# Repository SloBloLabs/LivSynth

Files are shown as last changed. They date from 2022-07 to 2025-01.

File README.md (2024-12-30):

# Youtube

Watch the related [Demo Video] on Youtube for a workout in musical context.

S54 (Liv's Synth - A Demo) (https://youtu.be/09B7NOryfzA)

Watch the corresponding [Video Manual] on Youtube for a detailed feature explanation.

S54 (Liv's Synth - A Demo) (https://youtu.be/lYTFUqn5oQk)

[Demo Video]: https://youtu.be/7tzhh7atj4o
[Video Manual]: https://youtu.be/lYTFUqn5oQk

# Build Instructions

How to convert a CubeMX / CubeIDE project to GNU ARM Toolchain with CMake, openocd and VS Code

Prerequisites

Available on PATH
 - ARM toolchain
 - make
 - cmake
 - openocd

VS Code extensions
 - MS C/C++
 - MS C/C++ Extension Pack
 - Cortex Debug

---

Workflow

Copy to project directory:
 - README.md
 - Makefile
 - CMakeLists.txt
 - cmake folder with arm toolchain cmake directives
 - .gitignore file
 - swvtrace.sh
 - svd file (optional)
 - folder .vscode/launch.json and adapt settings
 - folder "App"

then
 - Adapt settings in CMakeLists.txt header
 - rename myAppMain [.hpp/.cpp]
 - include myAppMain.hpp in Core/Src/main.c
 - add projectMain() to main.c (right before while loop)
 - right click CMakeLists.txt -> configure all projects
 - start coding

Tested on
 - Mac
 - Linux

2022-03-08: There is an issue using ARM Toolchain 11.2.1: https://community.arm.com/support-forums/f/compilers-and-libraries-forum/52377/internal-compiler-errors-with-arm-none-eabi-gcc-11-2-2022-02-on-macs-with-apple-silico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
Stick with 10.3 for now!!
2022-11-13: The issue is solved within Toolchain version 11.3.1

---

Upload to github
 - git init
 - git add .
 - git config user.name "<<username>>"
 - git config user.email "<<email>>"
 - git commit -m "First commit"
 - git branch -M main
 - git remote add origin https://github.com/SloBloLabs/<"ProjectRepo">.git
 - git push -u origin main

--

Update github access token
 - git remote remove origin
 - git remote add origin https://oauth2:<<new oauth token>>@github.com/<<username>>/<<reponame>>.git
 - git remote -v

--

Bake a new release on Github:
git tag <tagname> // e.g. v0.2.1
git push origin <tagname>

--
# STM32 USB Composite device

Composite USB interface:

1 configuration
3 interfaces (2*CDC + 1*MIDI)
6 endpoints

CDC:
 - 2 interfaces
   - 0: communications control
     - 1 endpoint 0x82
   - 1: communications data
     - 2 endpoints 0x01 + 0x81 (BULK)
 - 4 endpoints overall
   - EP0
   - EP1
   - EP3 (in only: 0x83)

MIDI:
 - 1 interface
   - 0: Audio/Streaming
     - 2 endpoints 0x02 + 0x83 (BULK)
 - 3 endpoints overall
   - EP0
   - EP2

# Build Instructions

Use the ibom tool inside the hardware section of the repository to track your work!
## Power
 - Place USB Micro Connector J21
 - Place all components from power section
   - U8
   - D12
   - FB1
   - U1
   - J24, J24, J12, J7
   - C49, C52, C32, C33, C1, C2, C3, C7
   - R1, R2, R11
   - SW7
 - Check voltages at J201, do proceed if everything is ok!

## Assembly of backside
 - assemble all components (except 5mm LEDs!) on the backside of the mainboard, preferably using the following order:
   - SMD components
   - resistors
   - diodes
   - DIP socket and DIP components
   - transistors (Q4/Q5, Q8/Q9 and Q11/Q12 must be matched)
   - tempco resistor
   - pin headers
   - capacitors

## Assemply of frontside
 - assemble potentiometers, trimmers, spacers and switches of the mainboard, DO NOT SOLDER THEM YET!
 - put the faceplate on top and make sure all components incl. trimmers fit into the wholes
 - fasten the M2.5 screws in the corners
 - turn the set around and solder everthing
 - remove the faceplate again

## Assmebly of speaker
 - First put screws from backside, hex nuts on the front side and tighten them
 - solder the hex nuts to the solder pads
 - apply two pieces of bell wire of about 5cm in lenght to the speakers solder pads
 - remove screws and mount the speaker to the frontside using the screws the other way around
 - if using the battery holder you may need to shorten one of the screws to make it fit
 - connect the loose ends of speaker wires to J4

## LEDs
 - assemble the 5mm LEDs on the backside
 - bend their heads in a 180° U-turn into the holes behind the transparent potentiometers, so they can emit as much light as possible into their shafts

## Flashing the firmware
 - make sure, dfu-util (https://dfu-util.sourceforge.net) is installed on your machine
   - alternatively, you can use stm32 cube programmer (https://www.st.com/en/development-tools/stm32cubeprog.html). I will not further explain this way, but it is a little more user friendly and pretty straight forward.
 - switch off the synthesizer
 - pull the run/program toggle switch next to the micro USB port to lower (program) position
 - connect a USB cable between the synth and your computer
 - switch on the synth again
 - execute the following command:
```
dfu-util -a 0 -s 0x08000000 -D <path to LivSynth.bin>
```
 - The output in the console shoud look similar to this:
```
dfu-util -a 0 -s 0x08000000 -D build/LivSynth.bin
dfu-util 0.11

Copyright 2005-2009 Weston Schmidt, Harald Welte and OpenMoko Inc.
Copyright 2010-2021 Tormod Volden and Stefan Schmidt
This program is Free Software and has ABSOLUTELY NO WARRANTY
Please report bugs to http://sourceforge.net/p/dfu-util/tickets/

dfu-util: Warning: Invalid DFU suffix signature
dfu-util: A valid DFU suffix will be required in a future dfu-util release
Opening DFU capable USB device...
Device ID 0483:df11
Device DFU version 011a
Claiming USB DFU Interface...
Setting Alternate Interface #0 ...
Determining device status...
DFU state(10) = dfuERROR, status(10) = Device's firmware is corrupt. It cannot return to run-time (non-DFU) operations
Clearing status
Determining device status...
DFU state(2) = dfuIDLE, status(0) = No error condition is present
DFU mode device DFU version 011a
Device returned transfer size 2048
DfuSe interface name: "Internal Flash  "
Downloading element to address = 0x08000000, size = 49412
Erase           [=========================] 100%        49412 bytes
Erase    done.
Download        [=========================] 100%        49412 bytes
Download done.
File downloaded successfully
```
 > Hint: if you are building the firmware from the repo, the DFU command is called by simply writing
```
make dfu
```
 - switch off the synth and remove the USB cable
 - pull the run/program switch up (run) again
 - switch on the synth
 - Click <kbd>shift</kbd> + <kbd>run</kbd> to enter sequence control mode
 - press and hold button <kbd>8</kbd> for more than 2 seconds. This will initialize the sequencer program in flash. The synth is now reset.
 - Press <kbd>run</kbd> again to get back to pattern mode

## Test & Calibration
 - connect a 9V center negative power supply to the barrel jack
 - switch on the device and wait a moment. Turn it off again if you see anything suspicious. ("smoke test")
 - At least the keyboard LEDs should light up in white colour and the LFO LEDs are blinking
### VCO
  - SAW amplitude
  - SQUARE amplitude
  - fine tune & tracking
    - Press a button and tune it to the lowest note (red) using the tune knob
    - Press another button and tune it to the red note two octaves higher
    - Press a third button and tune it to the highest red note
### VCA
  - balance...

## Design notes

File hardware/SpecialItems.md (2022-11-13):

SpecialItems

Alpha Potentiometers
RD901F-40-15K-B10K
RD901F-40-15K-B100K

see
https://www.thonk.co.uk/shop/alpha-9mm-pots-vertical-t18/
https://www.alibaba.com/product-detail/RD901F-40-15K-B10K-00DL1-alternative_1600283009362.html

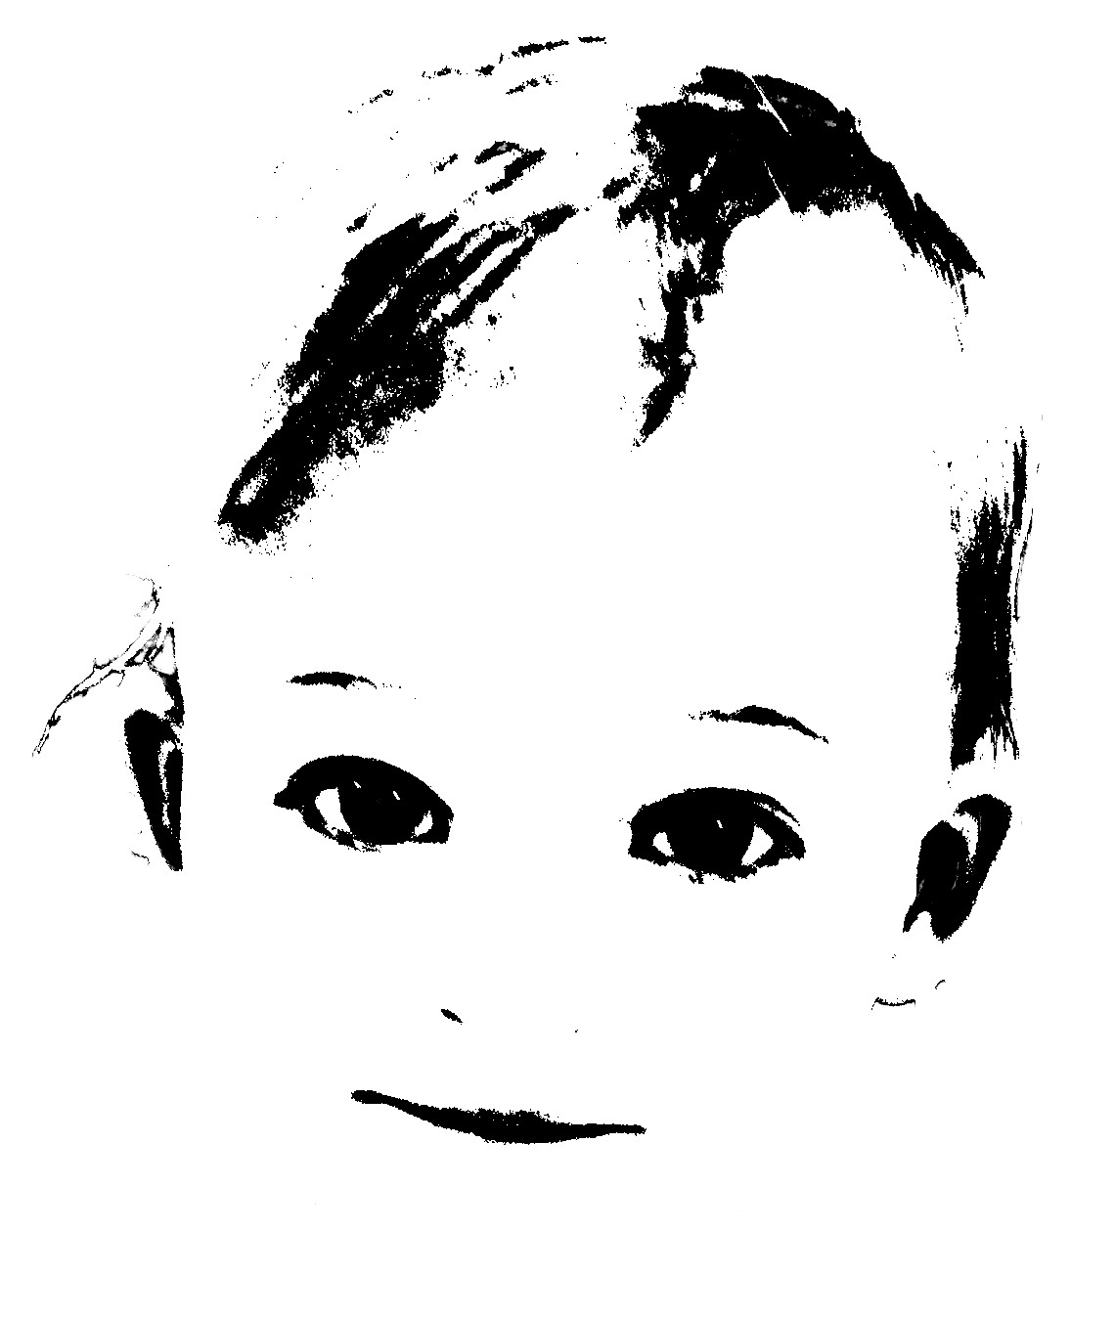
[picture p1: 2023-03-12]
hardware/Faceplate/LivGreyscale.JPG

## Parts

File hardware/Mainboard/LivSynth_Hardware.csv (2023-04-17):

Id | Designator | Footprint | Quantity | Designation | Supplier and ref
1 | RGB_Pot6,RGB_Pot5,RGB_Pot3,RGB_Pot8,RGB_Pot1,RGB_Pot9,RGB_Pot4,RGB_Pot2,RGB_Pot7 | TC002-N11AS2XT-RGB | 9 | TC002-N11AS2XT-RGB
2 | SW2 | SW_Toggle_MS500 | 1 | SW_SPST
3 | NT1,NT4,NT5,NT3,NT2 | NetTie-2_SMD_Pad0.5mm | 5 | NetTie_2
4 | RV17,RV16,RV15,RV2 | Potentiometer_Bourns_3296W_Vertical | 4 | 100K
5 | LS1 | LSM-50M NO-B | 1 | LSM-50M/NO-B 8R (<32R) 1W
6 | SW6 | E-Switch_TL1105SP | 1 | SW_Push
7 | RV22,RV19,RV13,RV14,RV3,RV8,RV18,RV20 | Alpha_RD901F | 8 | 100K
8 | RV7,RV6,RV10,RV5,RV11 | RV141F-40-20BL | 5 | 100K
9 | RV1 | Potentiometer_Bourns_3296W_Vertical | 1 | 1K
10 | SW4,SW3,SW1 | SW_Toggle_MS500 | 3 | SW_SPDT
11 | RV21 | Alpha_RD901F | 1 | 10K
12 | RV9,RV4 | RV141F-40-20BL | 2 | 10K
13 | J3,J1,J2 | Thonkiconn_PJ398SM | 3 | PJ398SM
14 | H2,H1,H6,H5 | MountingHole_3.2mm_M3 | 4 | MountingHole
15 | RV12 | Potentiometer_Bourns_3296W_Vertical | 1 | 100
16 | R46,R16,R25,R27,R35,R48,R15,R45 | R_Axial_DIN0207_L6.3mm_D2.5mm_P7.62mm_Horizontal | 8 | 1K
17 | D10,D5,D8,D9,D2,D1 | LED_D5.0mm | 6 | LED
18 | R75,R76,R70,R67 | R_Axial_DIN0207_L6.3mm_D2.5mm_P7.62mm_Horizontal | 4 | 100
19 | C43,C7,C58,C37,C34,C59,C35,C18,C26,C61,C12,C17,C62,C27,C31,C6,C4,C16,C30,C3 | C_Rect_L7.2mm_W2.5mm_P5.00mm_FKS2_FKP2_MKS2_MKP2 | 20 | 100n
20 | R77 | R_Axial_DIN0207_L6.3mm_D2.5mm_P7.62mm_Horizontal | 1 | 4k7
21 | R83,R80,R10,R72,R66,R40,R11,R37,R26,R21,R32,R2,R78,R13,R1,R64,R87,R22,R79,R19,R82,R4,R47,R56,R81,R12,R39,R3,R38,R51 | R_Axial_DIN0207_L6.3mm_D2.5mm_P7.62mm_Horizontal | 30 | 100K
22 | R42,R31,R36,R24,R54,R33 | R_Axial_DIN0207_L6.3mm_D2.5mm_P7.62mm_Horizontal | 6 | 2K
23 | R109,R30,R106,R107,R105,R29,R34,R73,R69,R89,R113,R114,R111,R112,R108,R68,R110 | R_Axial_DIN0207_L6.3mm_D2.5mm_P7.62mm_Horizontal | 17 | 10K
24 | R125,R131,R103,R98,R101,R129,R117,R121,R100,R91,R127,R99,R123,R14,R88,R104,R102,R119,R97 | R_Axial_DIN0207_L6.3mm_D2.5mm_P7.62mm_Horizontal | 19 | 220
25 | R41 | R_Axial_DIN0207_L6.3mm_D2.5mm_P7.62mm_Horizontal | 1 | 6K2
26 | R7,R9 | R_Axial_DIN0207_L6.3mm_D2.5mm_P7.62mm_Horizontal | 2 | 20K
27 | U2,U4,U6,U1,U5 | SOIC-14_3.9x8.7mm_P1.27mm | 5 | TL074
28 | Q6,Q12,Q15,Q4,Q11,Q5,Q10,Q13,Q7,Q16,Q1,Q2,Q14,Q17 | TO-92_Inline | 14 | 2N3904
29 | C14,C23,C24 | C_Rect_L7.2mm_W4.5mm_P5.00mm_FKS2_FKP2_MKS2_MKP2 | 3 | 270n
30 | C1,C9,C41,C19,C2,C33,C32 | C_Rect_L7.2mm_W5.5mm_P5.00mm_FKS2_FKP2_MKS2_MKP2 | 7 | 1u
31 | D12 | D_SMC_Handsoldering | 1 | SS310
32 | R90,R130,R122,R124,R126,R120,R118,R128,R116 | R_Axial_DIN0207_L6.3mm_D2.5mm_P7.62mm_Horizontal | 9 | 470
33 | R28,R74,R92,R52,R93 | R_Axial_DIN0207_L6.3mm_D2.5mm_P7.62mm_Horizontal | 5 | 4K7
34 | BT1 | BatteryHolder_Eagle_12BH611-GR | 1 | 9V
35 | R58 | R_Axial_DIN0207_L6.3mm_D2.5mm_P7.62mm_Horizontal | 1 | 150K
36 | U14,U13 | SOIC-16_3.9x9.9mm_P1.27mm | 2 | 74HC165
37 | J21 | USB_Micro-B_Wuerth_629105150521 | 1 | USB_B_Micro
38 | J13,J9,J16,J15,J19,J11,J18,J22,J17,J10,J8 | PinHeader_1x02_P2.54mm_Vertical | 11 | Jumper
39 | D11,D6,D7 | D_DO-35_SOD27_P7.62mm_Horizontal | 3 | 1N4148
40 | R59,R18,R17 | R_Axial_DIN0207_L6.3mm_D2.5mm_P7.62mm_Horizontal | 3 | 47K
41 | J24 | PinHeader_1x02_P2.54mm_Vertical | 1 | 3V3
42 | C10 | CP_Radial_D8.0mm_P3.50mm | 1 | 33u
43 | R44 | R_Axial_DIN0207_L6.3mm_D2.5mm_P7.62mm_Horizontal | 1 | 68K
44 | Q8,Q9 | TO-92_Inline | 2 | 2N3906
45 | R71 | R_Axial_DIN0207_L6.3mm_D2.5mm_P7.62mm_Horizontal | 1 | 68k
46 | R60 | R_Axial_DIN0207_L6.3mm_D2.5mm_P7.62mm_Horizontal | 1 | 100k
47 | U10,U11 | TSSOP-28_4.4x9.7mm_P0.65mm | 2 | PCA9685PW
48 | SW8,SW7 | SW_E-Switch_EG1224_SPDT_Angled | 2 | SW_SPDT
49 | C49,C45,C15 | CP_Radial_D8.0mm_P3.50mm | 3 | 10u
50 | C29 | CP_Radial_D8.0mm_P3.50mm | 1 | 470u
51 | R49 | R_Axial_DIN0207_L6.3mm_D2.5mm_P7.62mm_Horizontal | 1 | 820K
52 | J7 | BarrelJack_CUI_PJ-102AH_Horizontal | 1 | Barrel_Jack_Switch
53 | R63,R62 | R_Axial_DIN0207_L6.3mm_D2.5mm_P7.62mm_Horizontal | 2 | 1M
54 | C5,C20 | C_Rect_L7.2mm_W2.5mm_P5.00mm_FKS2_FKP2_MKS2_MKP2 | 2 | 1n
55 | R50 | R_Axial_DIN0207_L6.3mm_D2.5mm_P7.62mm_Horizontal | 1 | 100R
56 | R55 | R_Axial_DIN0207_L6.3mm_D2.5mm_P7.62mm_Horizontal | 1 | 2K2
57 | Y1 | Crystal_SMD_3225-4Pin_3.2x2.5mm_HandSoldering | 1 | ABM8-16.000MHZ-D1X-T
58 | U7 | SOP-16_3.9x9.9mm_P1.27mm | 1 | LM13700
59 | J25 | PinHeader_1x02_P2.54mm_Vertical | 1 | 9V
60 | R85,R86 | R_Axial_DIN0207_L6.3mm_D2.5mm_P7.62mm_Horizontal | 2 | 2K7
61 | R23,R43 | R_Axial_DIN0207_L6.3mm_D2.5mm_P7.62mm_Horizontal | 2 | 470K
62 | R6,R5 | R_Axial_DIN0207_L6.3mm_D2.5mm_P7.62mm_Horizontal | 2 | 360
63 | C21,C13,C36 | C_Rect_L7.2mm_W2.5mm_P5.00mm_FKS2_FKP2_MKS2_MKP2 | 3 | 10n
64 | R57 | R_Axial_DIN0207_L6.3mm_D2.5mm_P7.62mm_Horizontal | 1 | 24K
65 | C11,C8 | C_Disc_D3.0mm_W1.6mm_P2.50mm | 2 | 1p
66 | TH1 | R_Axial_DIN0207_L6.3mm_D2.5mm_P7.62mm_Horizontal | 1 | 2K 3300ppm LT16S202F33
67 | FB1 | L_0603_1608Metric | 1 | 120R@100MHz
68 | R61 | R_Axial_DIN0207_L6.3mm_D2.5mm_P7.62mm_Horizontal | 1 | 10R
69 | C25 | C_Rect_L7.2mm_W5.5mm_P5.00mm_FKS2_FKP2_MKS2_MKP2 | 1 | 270n
70 | R84 | R_Axial_DIN0207_L6.3mm_D2.5mm_P7.62mm_Horizontal | 1 | 330K
71 | R8,R65 | R_Axial_DIN0207_L6.3mm_D2.5mm_P7.62mm_Horizontal | 2 | 390
72 | R53 | R_Axial_DIN0207_L6.3mm_D2.5mm_P7.62mm_Horizontal | 1 | 8K2
73 | R20 | R_Axial_DIN0207_L6.3mm_D2.5mm_P7.62mm_Horizontal | 1 | 82K
74 | C22 | CP_Radial_D8.0mm_P3.50mm | 1 | 4u7
75 | C52 | CP_Radial_D8.0mm_P3.50mm | 1 | 22u
76 | C28 | C_Disc_D3.0mm_W1.6mm_P2.50mm | 1 | 47p
77 | U9 | LQFP-64_10x10mm_P0.5mm | 1 | STM32F405RGT6
78 | J12 | PinHeader_1x02_P2.54mm_Vertical | 1 | VGND
79 | D3 | LED_D5.0mm-4_RGB | 1 | LED_RKGB
80 | U8 | SOT-223-3_TabPin2 | 1 | LM1117-3.3
81 | U3 | DIP-8_W7.62mm_Socket | 1 | LM386

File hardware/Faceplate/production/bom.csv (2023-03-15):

Designator | Footprint | Quantity | Value | LCSC Part #
_250, _249, _248, _247, _246, _245, _244, _243, _242, _241, _240, _239, _238, _237, _236, _235, _234, _233, _232, _231, _230, _229, _228, _227, _226, _225, _224, _223, _222, _221, _220, _219, _218, _217, _216, _215, _214, _213, _212, _211, _210, _209, _208, _207, _206, _205, _204, _203, _202, _201, _200, _199, _198, _197, _196, _195, _194, _193, _192, _191, _190, _189, _188, _187, _186, _185, _184, _183, _182, _181, _180, _179, _178, _177, _176, _175, _174, _173, _172, _171, _170, _169, _168, _167, _166, _165, _164, _163, _162, _161, _160, _159, _158, _157, _156, _155, _154, _153, _152, _151, _150, _149, _148, _147, _146, _145, _144, _143, _142, _141, _140, _139, _138, _137, _136, _135, _134, _133, _132, _131, _130, _129, _128, _127, _126, _125, _124, _123, _122, _121, _120, _119, _118, _117, _116, _115, _114, _113, _112, _111, _110, _109, _108, _107, _106, _105, _104, _103, _102, _101, _100, _99, _98, _97, _96, _95, _94, _93, _92, _91, _90, _89, _88, _87, _86, _85, _84, _83, _82, _81, _80, _79, _78, _77, _76, _75, _74, _73, _72, _71, _70, _69, _68, _67, _66, _65, _64, _63, _62, _61, _60, _59, _58, _57, _56, _55, _54, _53, _52, _51, _50, _49, _48, _47, _46, _45, _44, _43, _42, _41, _40, _39, _38, _37, _36, _35, _34, _33, _32, _31, _30, _29, _28, _27, _26, _25, _24, _23, _22, _21, _20, _19, _18, _17, _16, _15, _14, _13, _12, _11, _10, _9, _8, _7, _6, _5, _4, _3, _2, |  | 250
H1, H2, H5, H6 | MountingHole_3.2mm_M3 | 4 | MountingHole

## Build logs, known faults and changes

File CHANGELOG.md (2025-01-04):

v0.2.5
- Play incoming midi notes in idle mode
- Store last incoming midi note to selected step
- Cosmetics in USB device descriptor

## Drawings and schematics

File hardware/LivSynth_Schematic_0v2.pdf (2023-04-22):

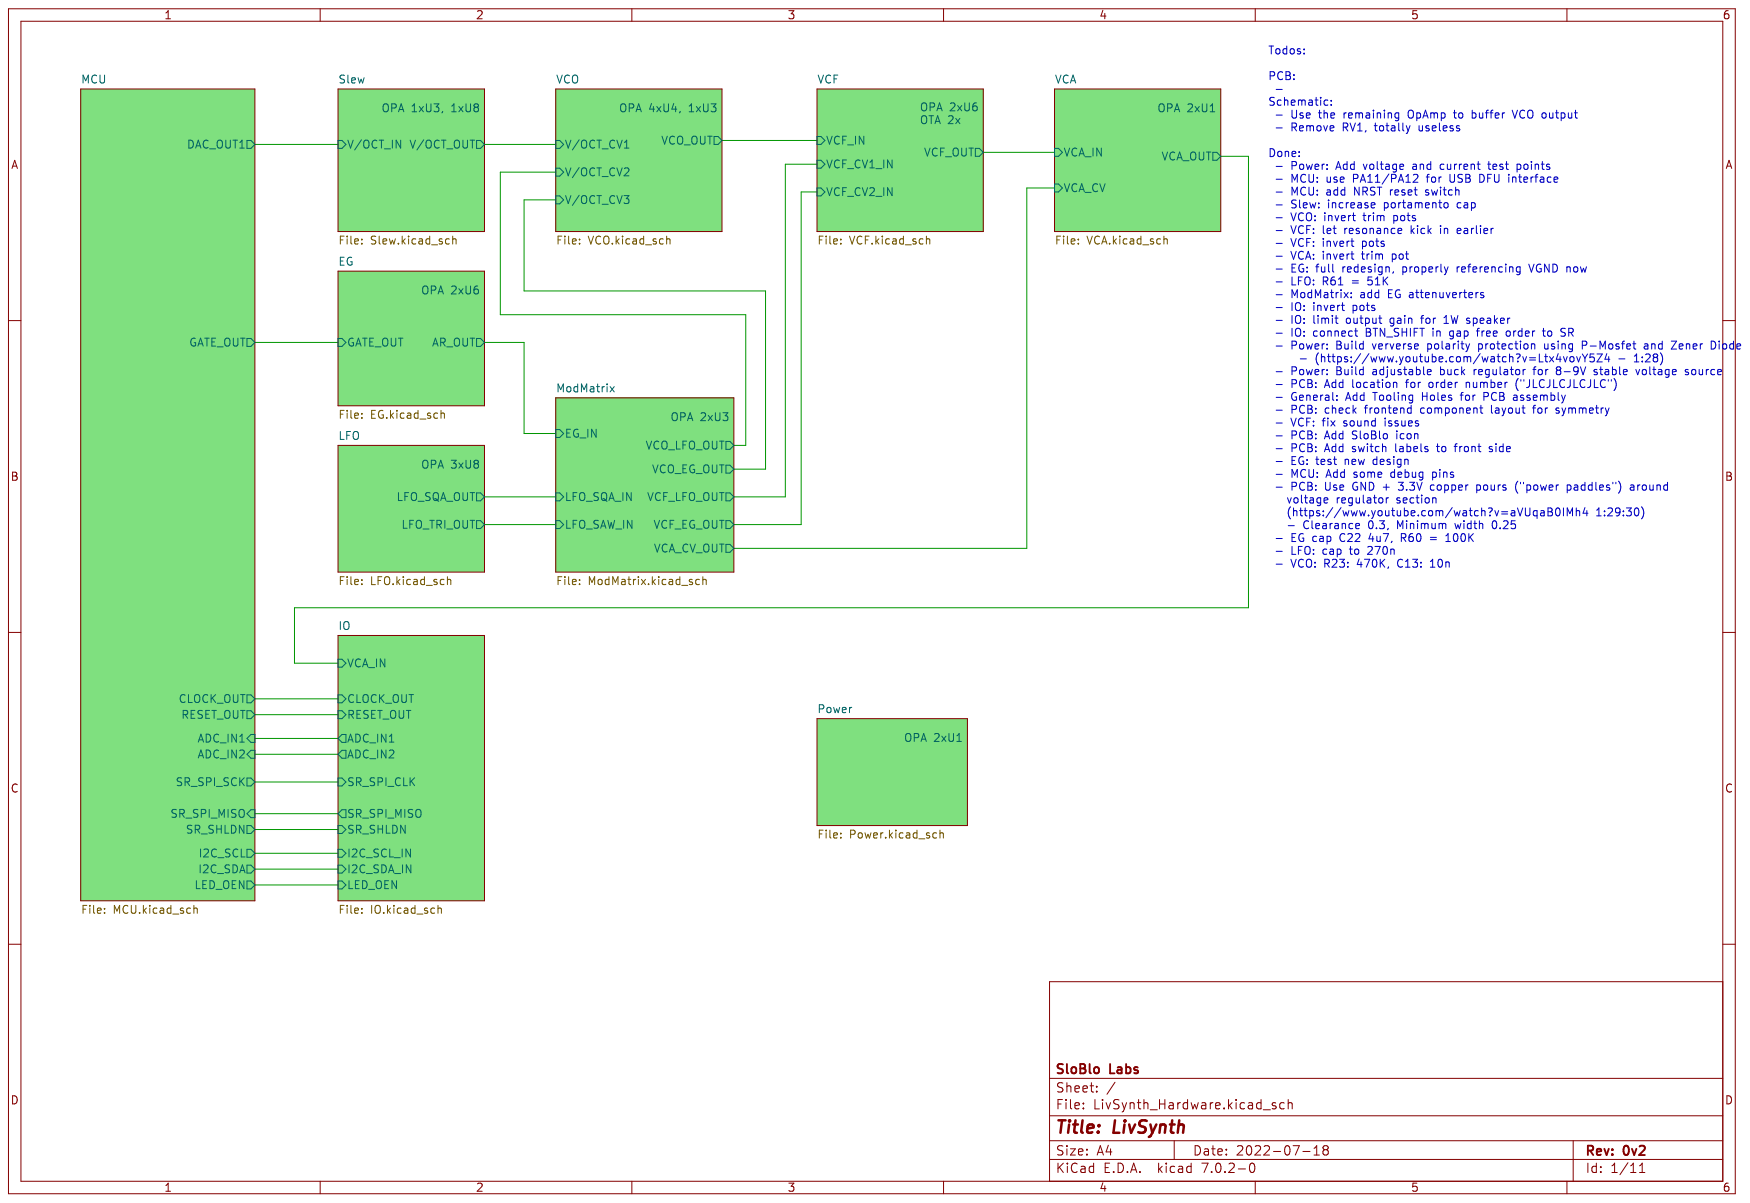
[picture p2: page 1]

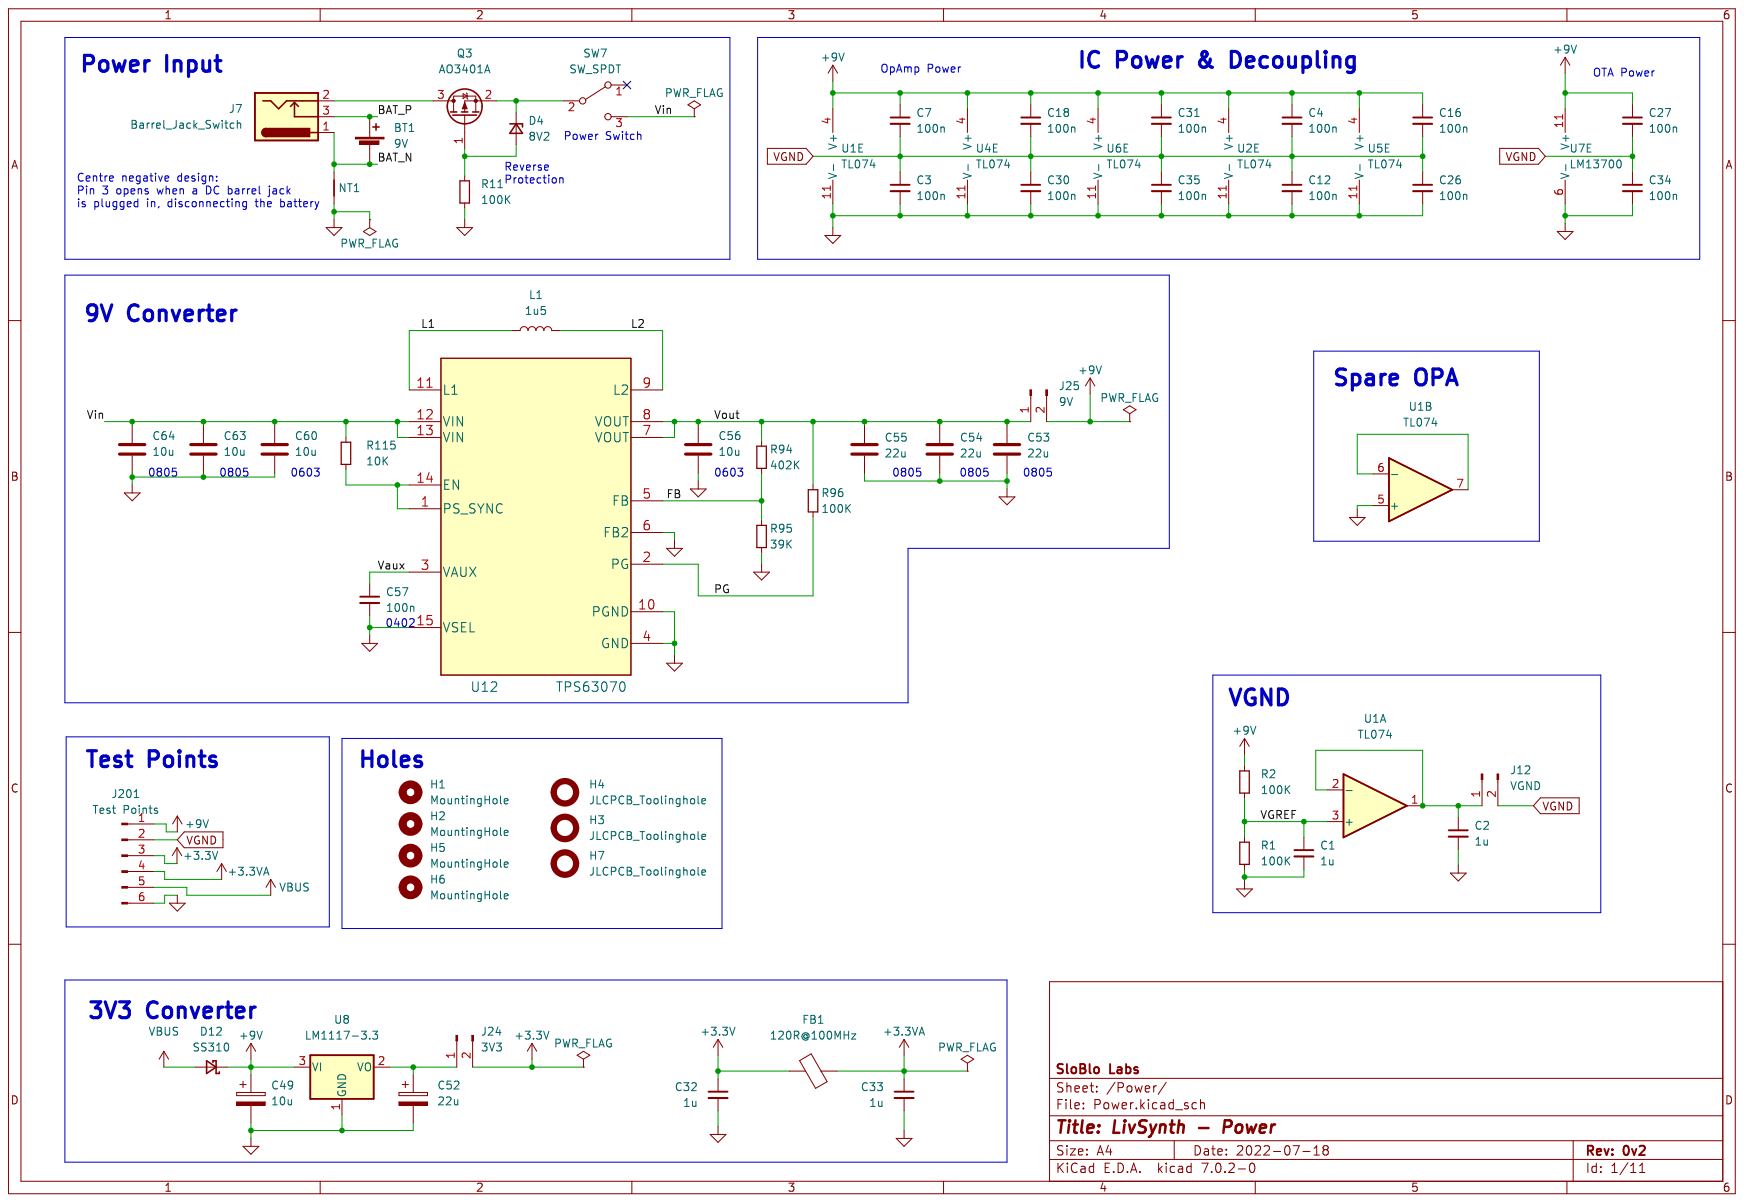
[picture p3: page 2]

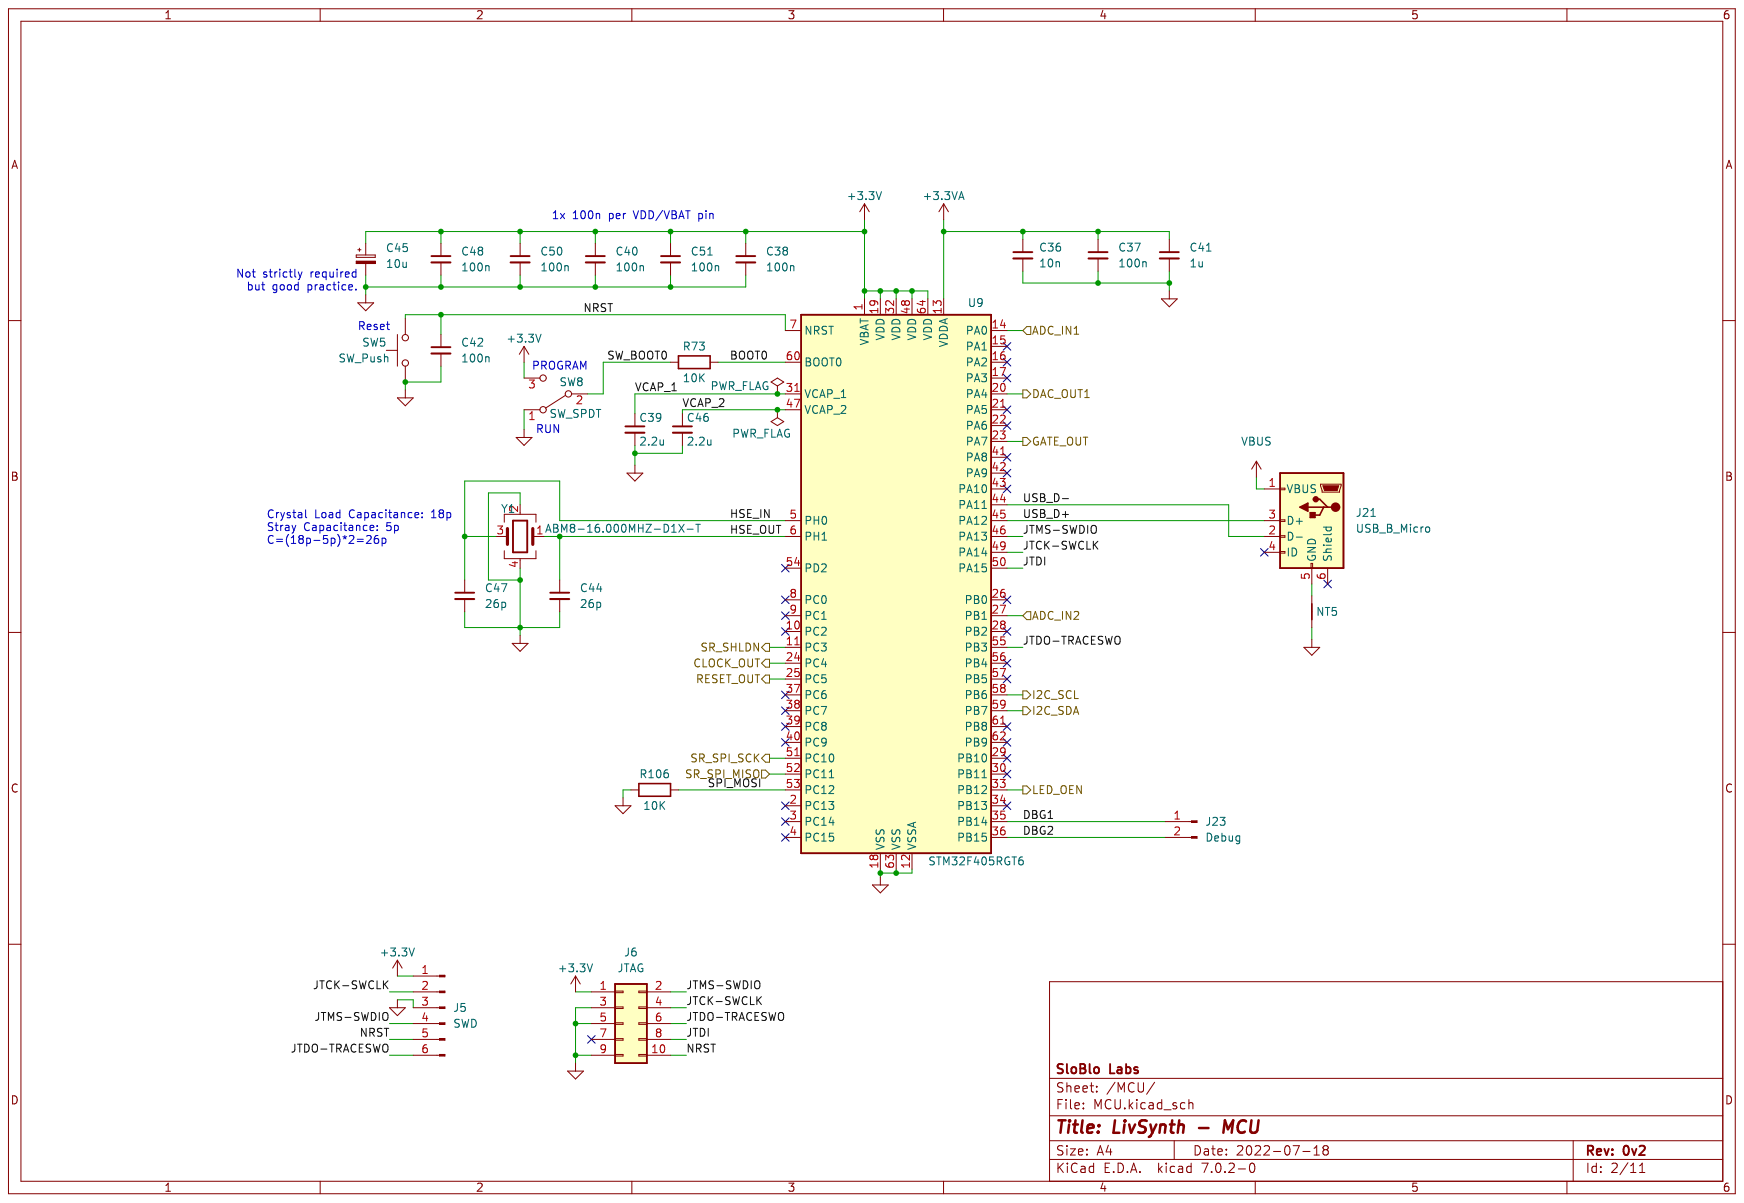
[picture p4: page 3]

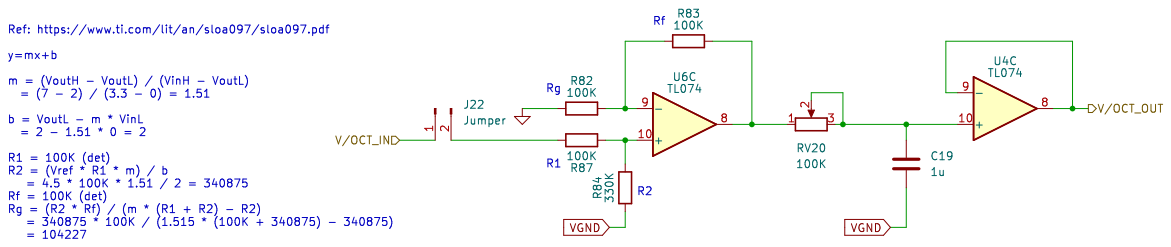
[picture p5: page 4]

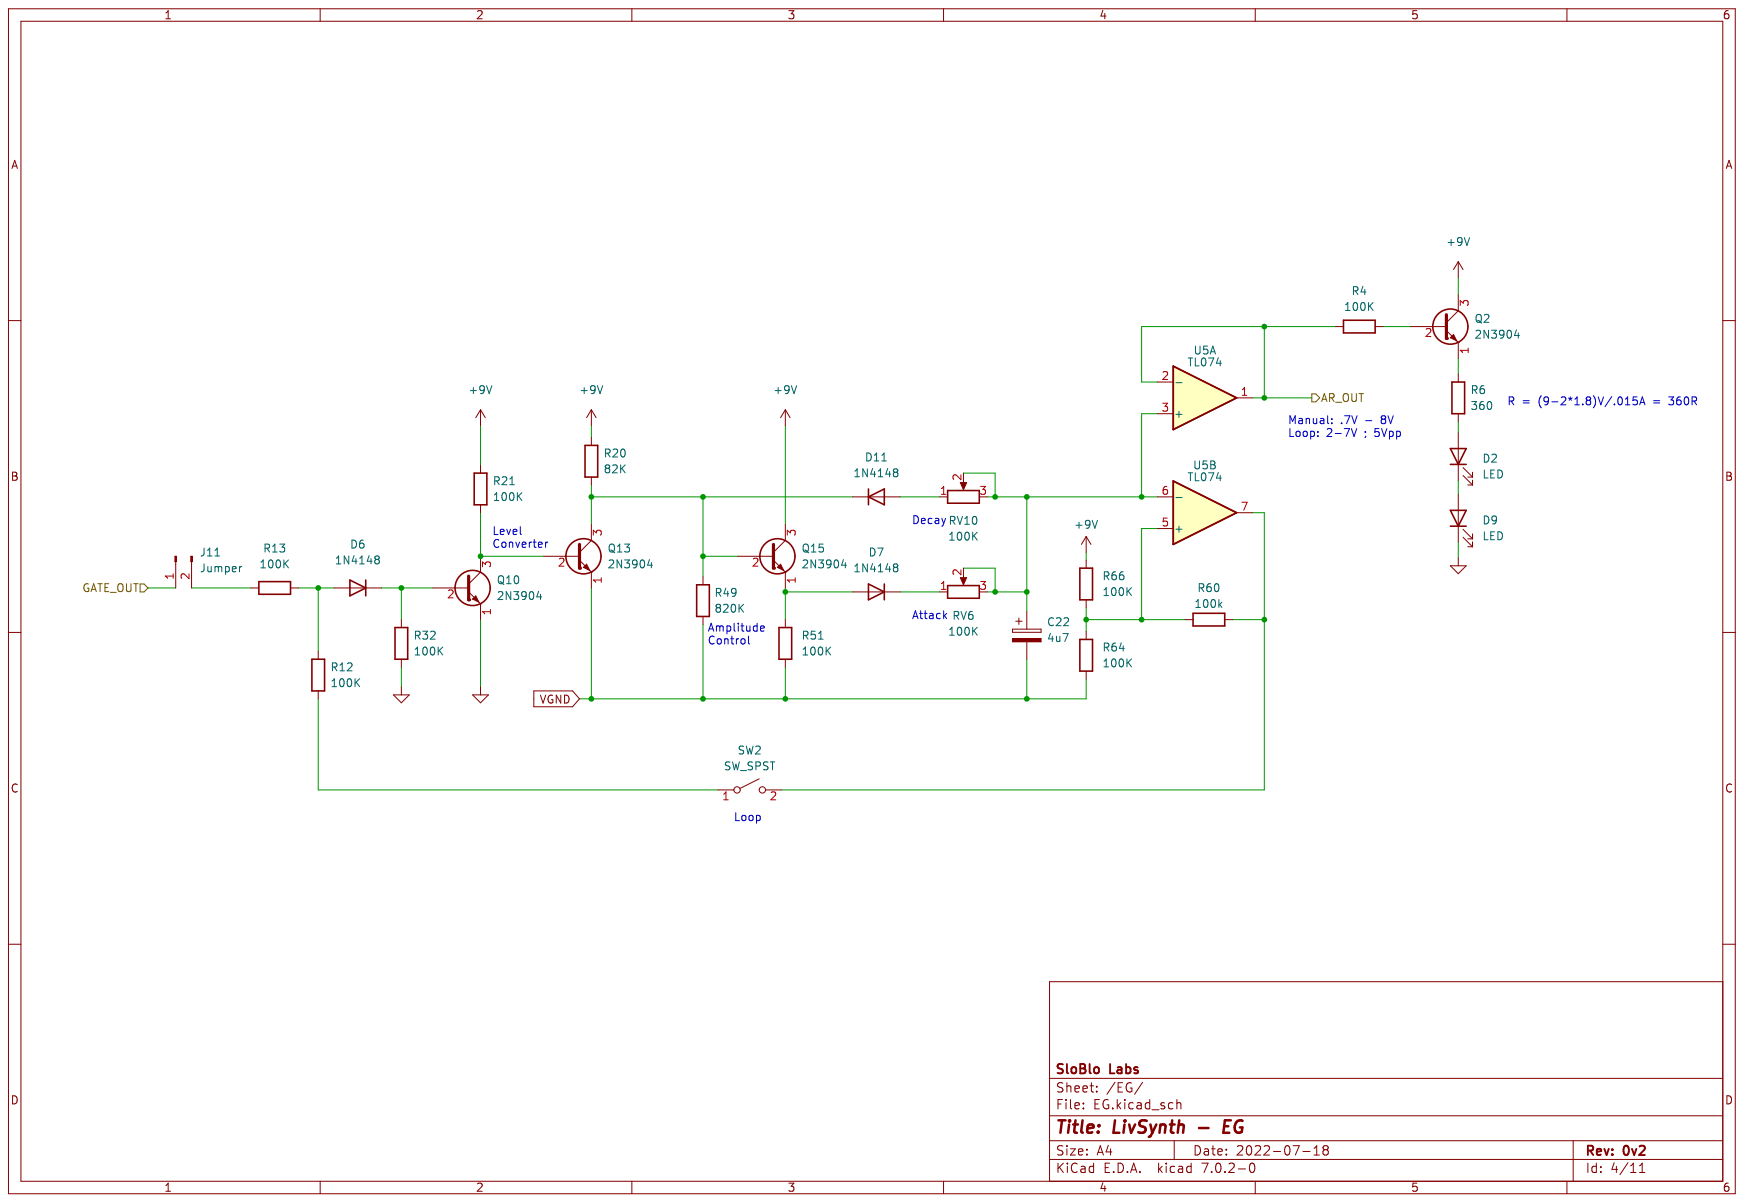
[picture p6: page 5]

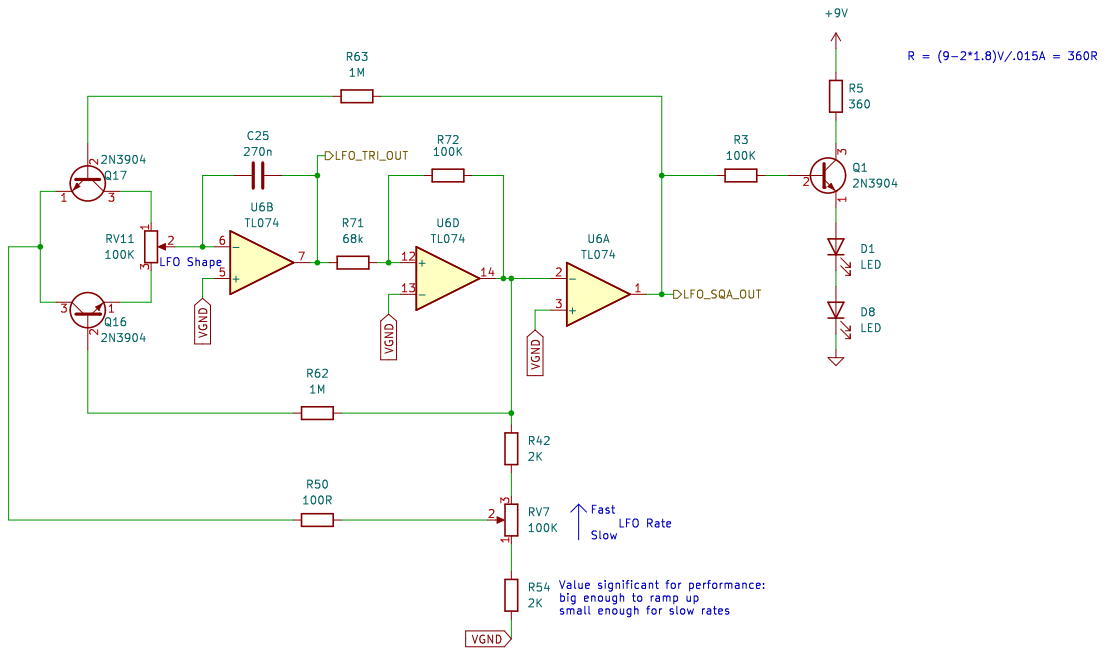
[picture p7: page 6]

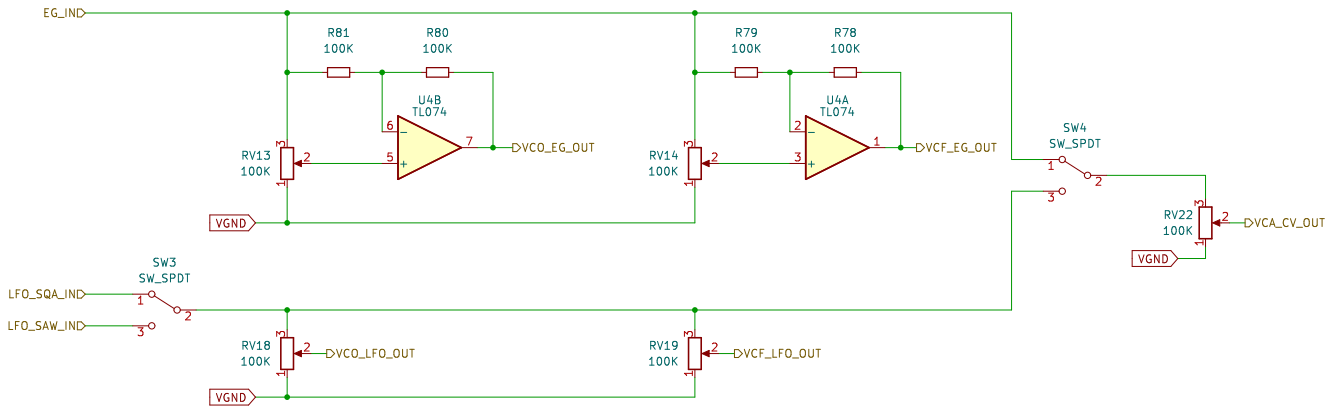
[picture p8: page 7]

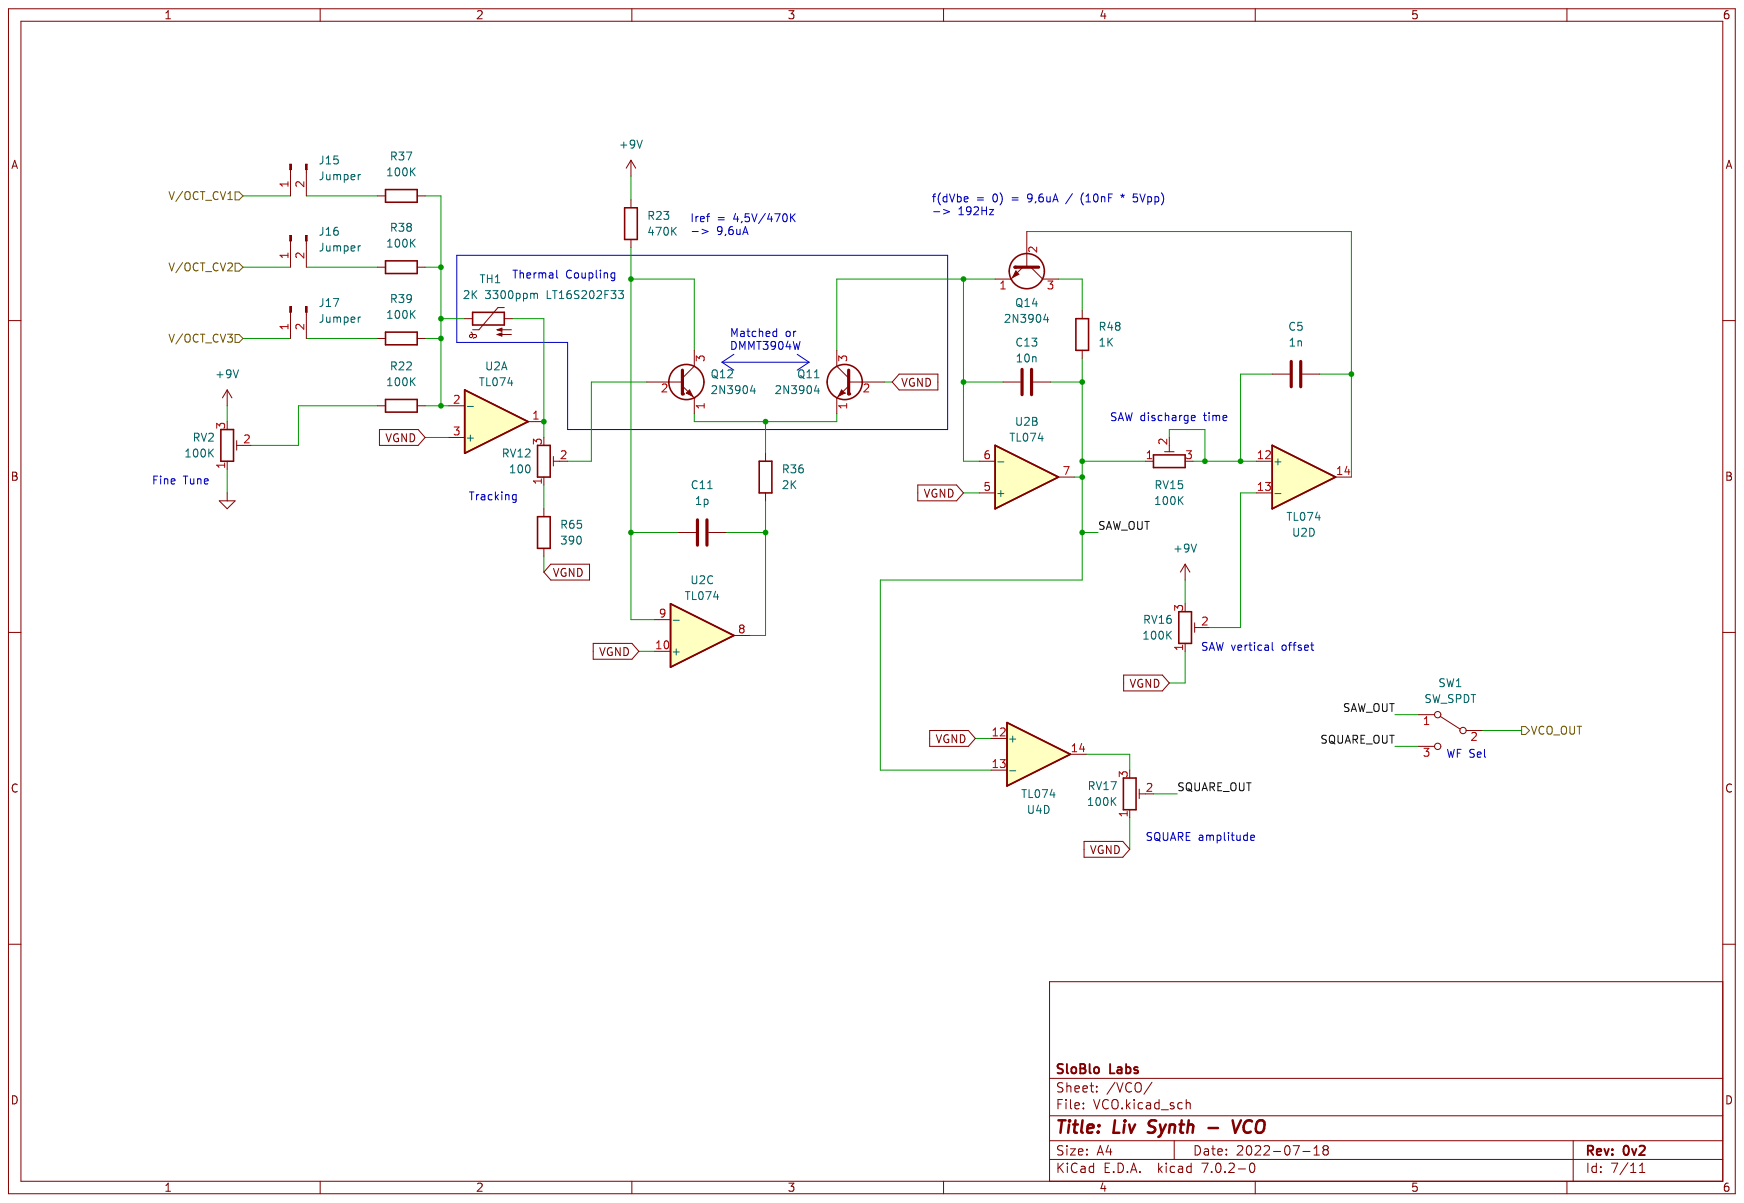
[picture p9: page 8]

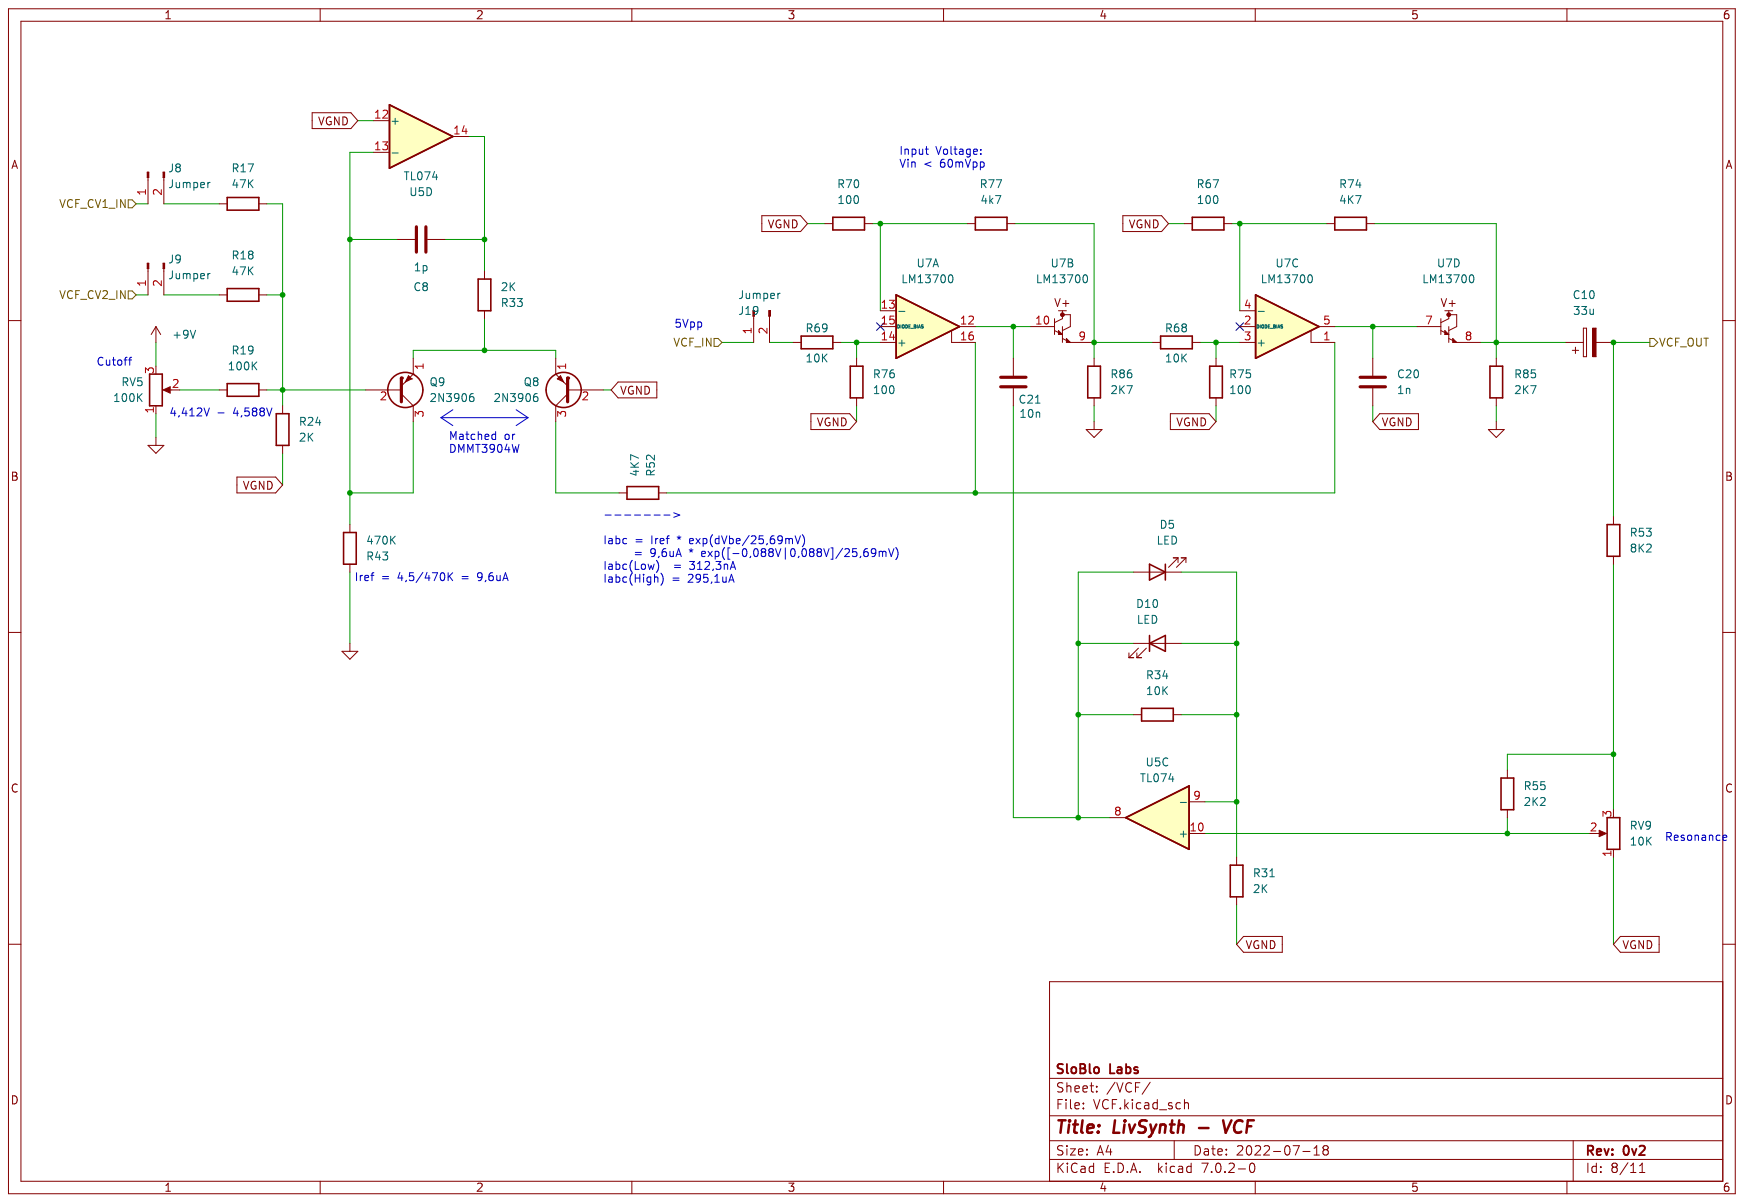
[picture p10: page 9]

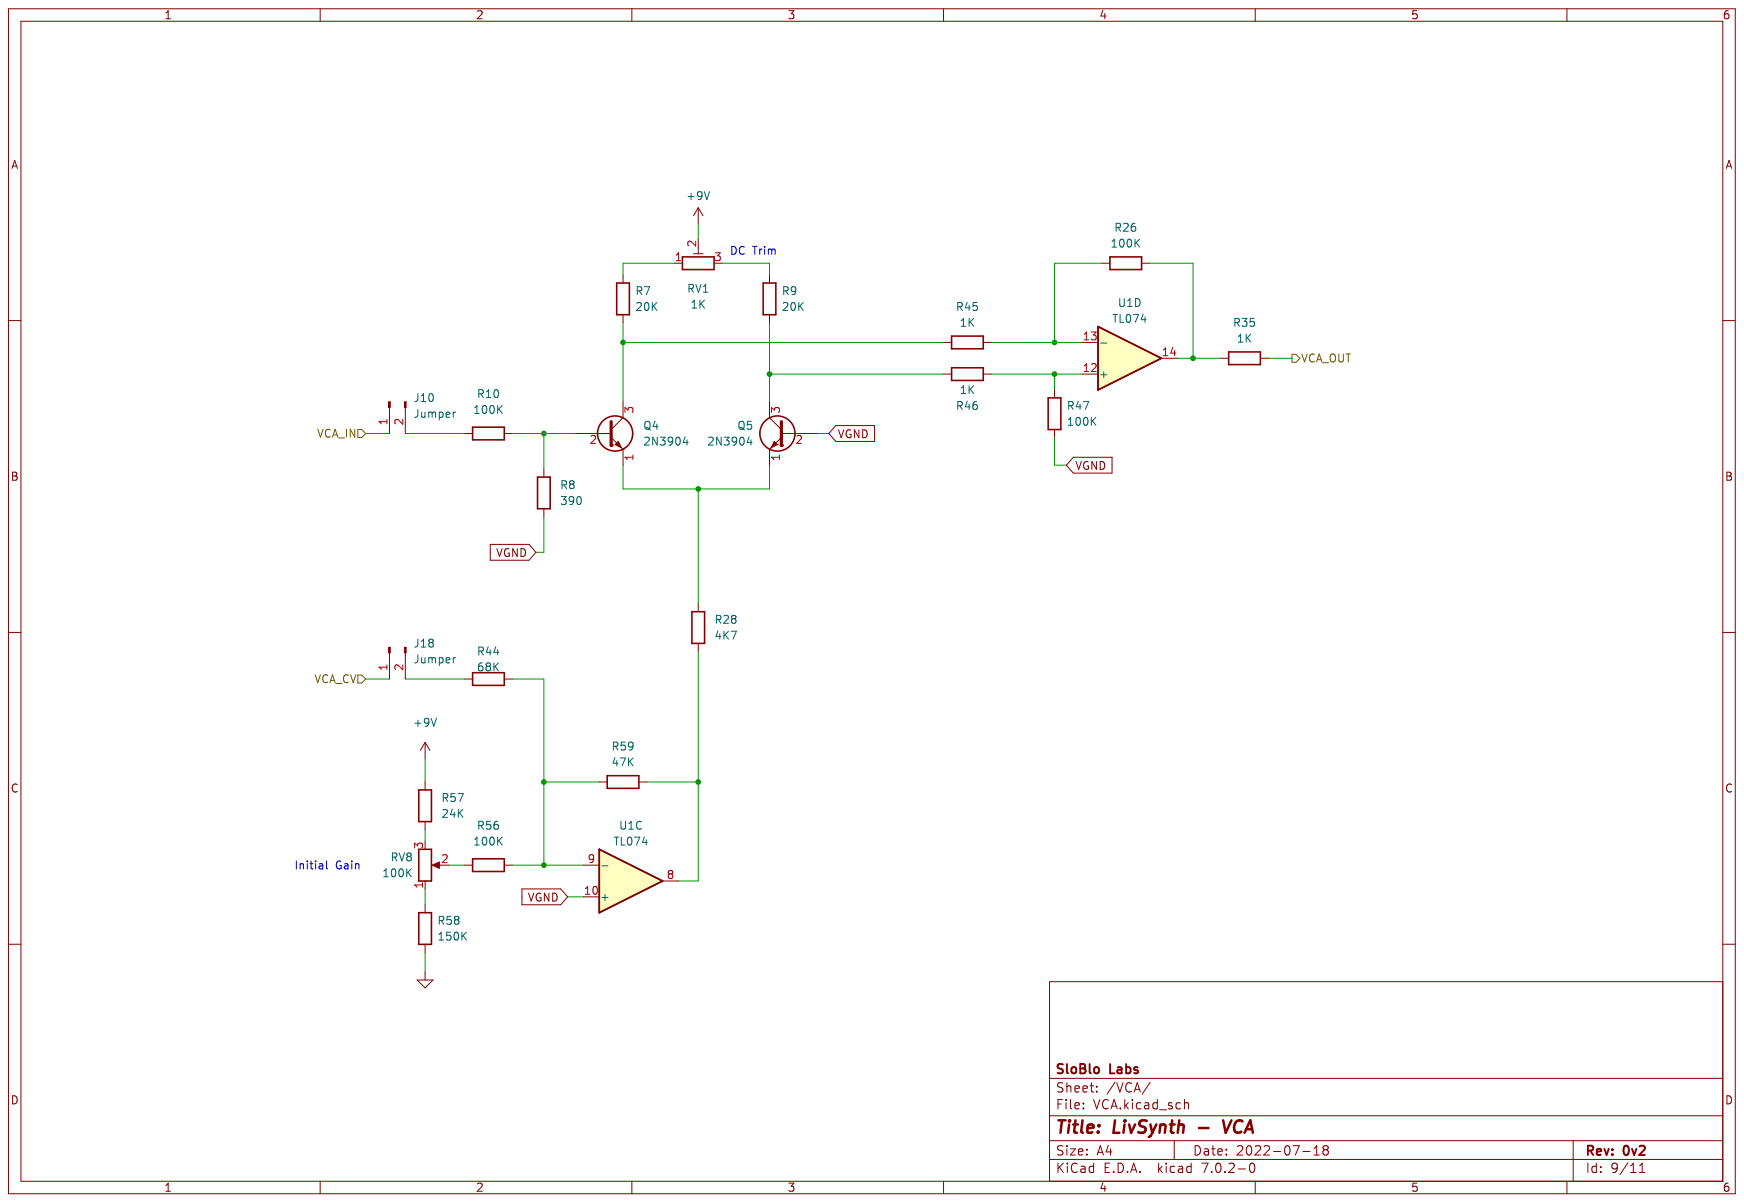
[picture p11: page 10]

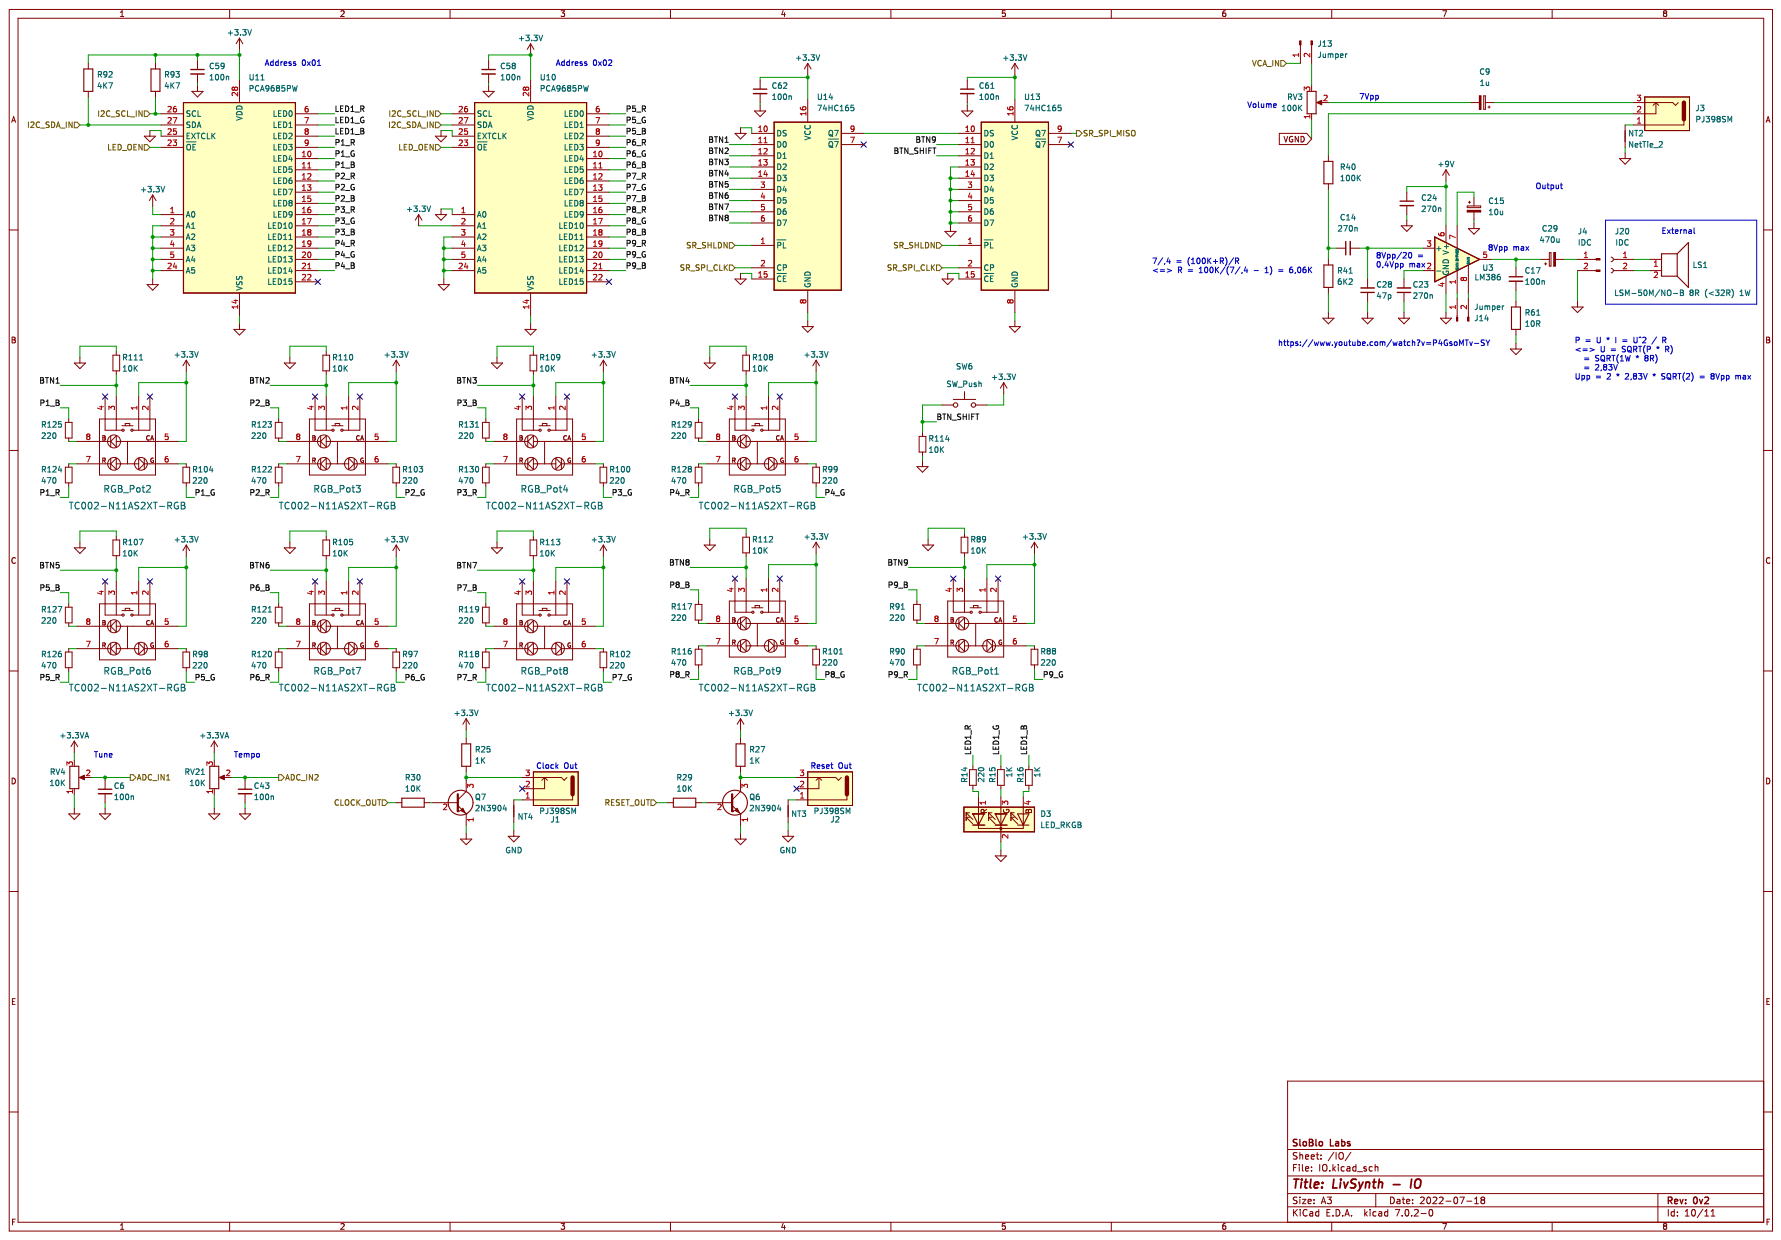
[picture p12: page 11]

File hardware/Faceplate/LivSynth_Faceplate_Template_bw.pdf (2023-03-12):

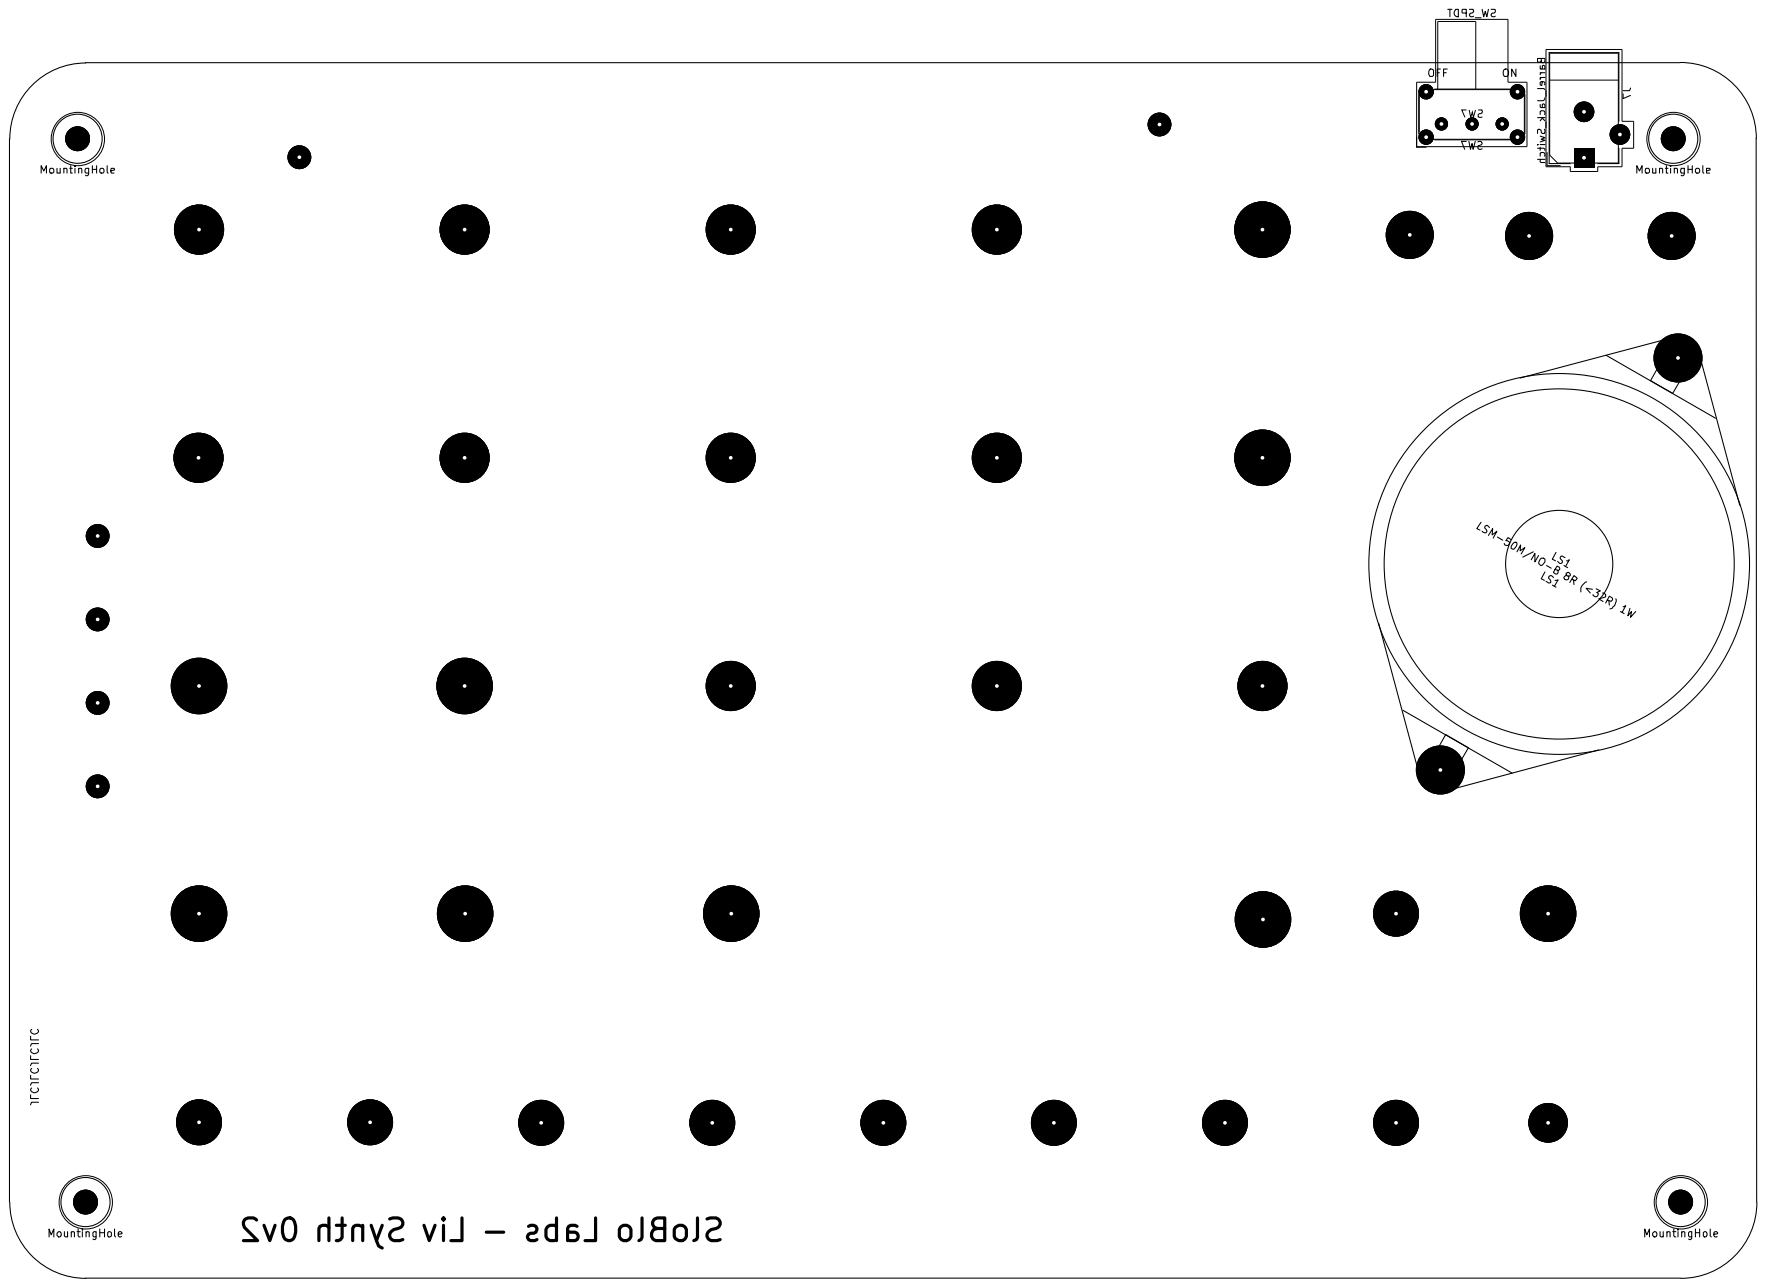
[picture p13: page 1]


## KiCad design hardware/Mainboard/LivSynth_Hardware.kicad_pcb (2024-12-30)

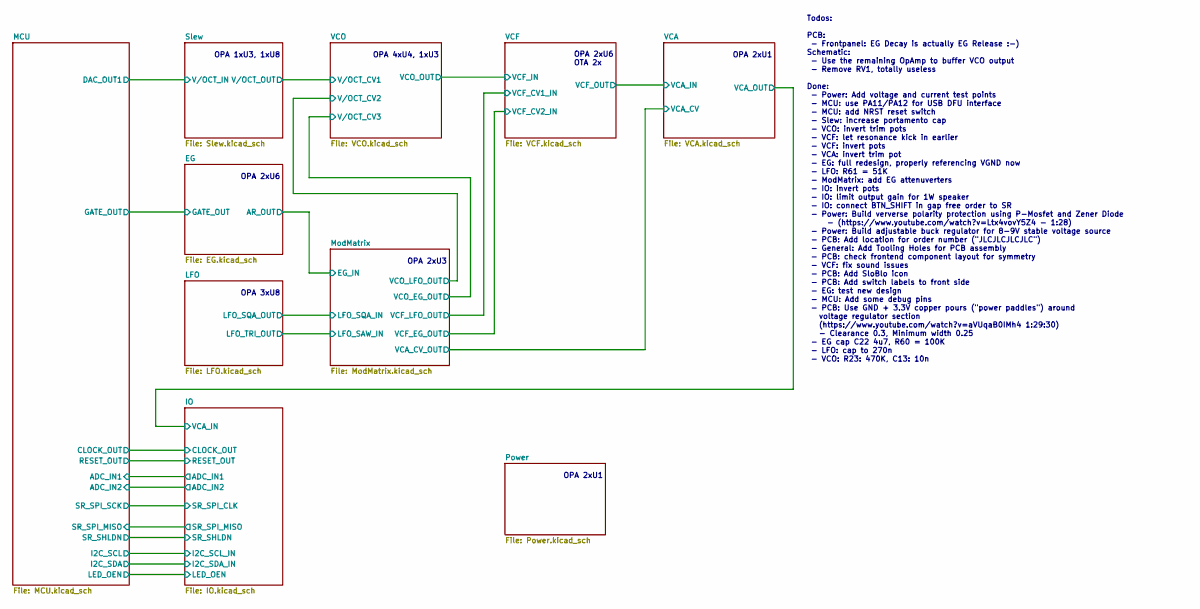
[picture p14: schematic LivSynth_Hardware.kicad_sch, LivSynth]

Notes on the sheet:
OPA 1xU3, 1xU8
OPA 2xU6
OPA 3xU8
OPA 2xU3
Todos: PCB: - Frontpanel: EG Decay is actually EG Release :-) Schematic: - Use the remaining OpAmp to buffer VCO output - Remove RV1, totally useless Done: - Power: Add voltage and current test points - MCU: use PA11/PA12 for USB DFU interface - MCU: add NRST reset switch - Slew: increase portament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
OPA 2xU6 OTA 2x
OPA 2xU1
OPA 4xU4, 1xU3

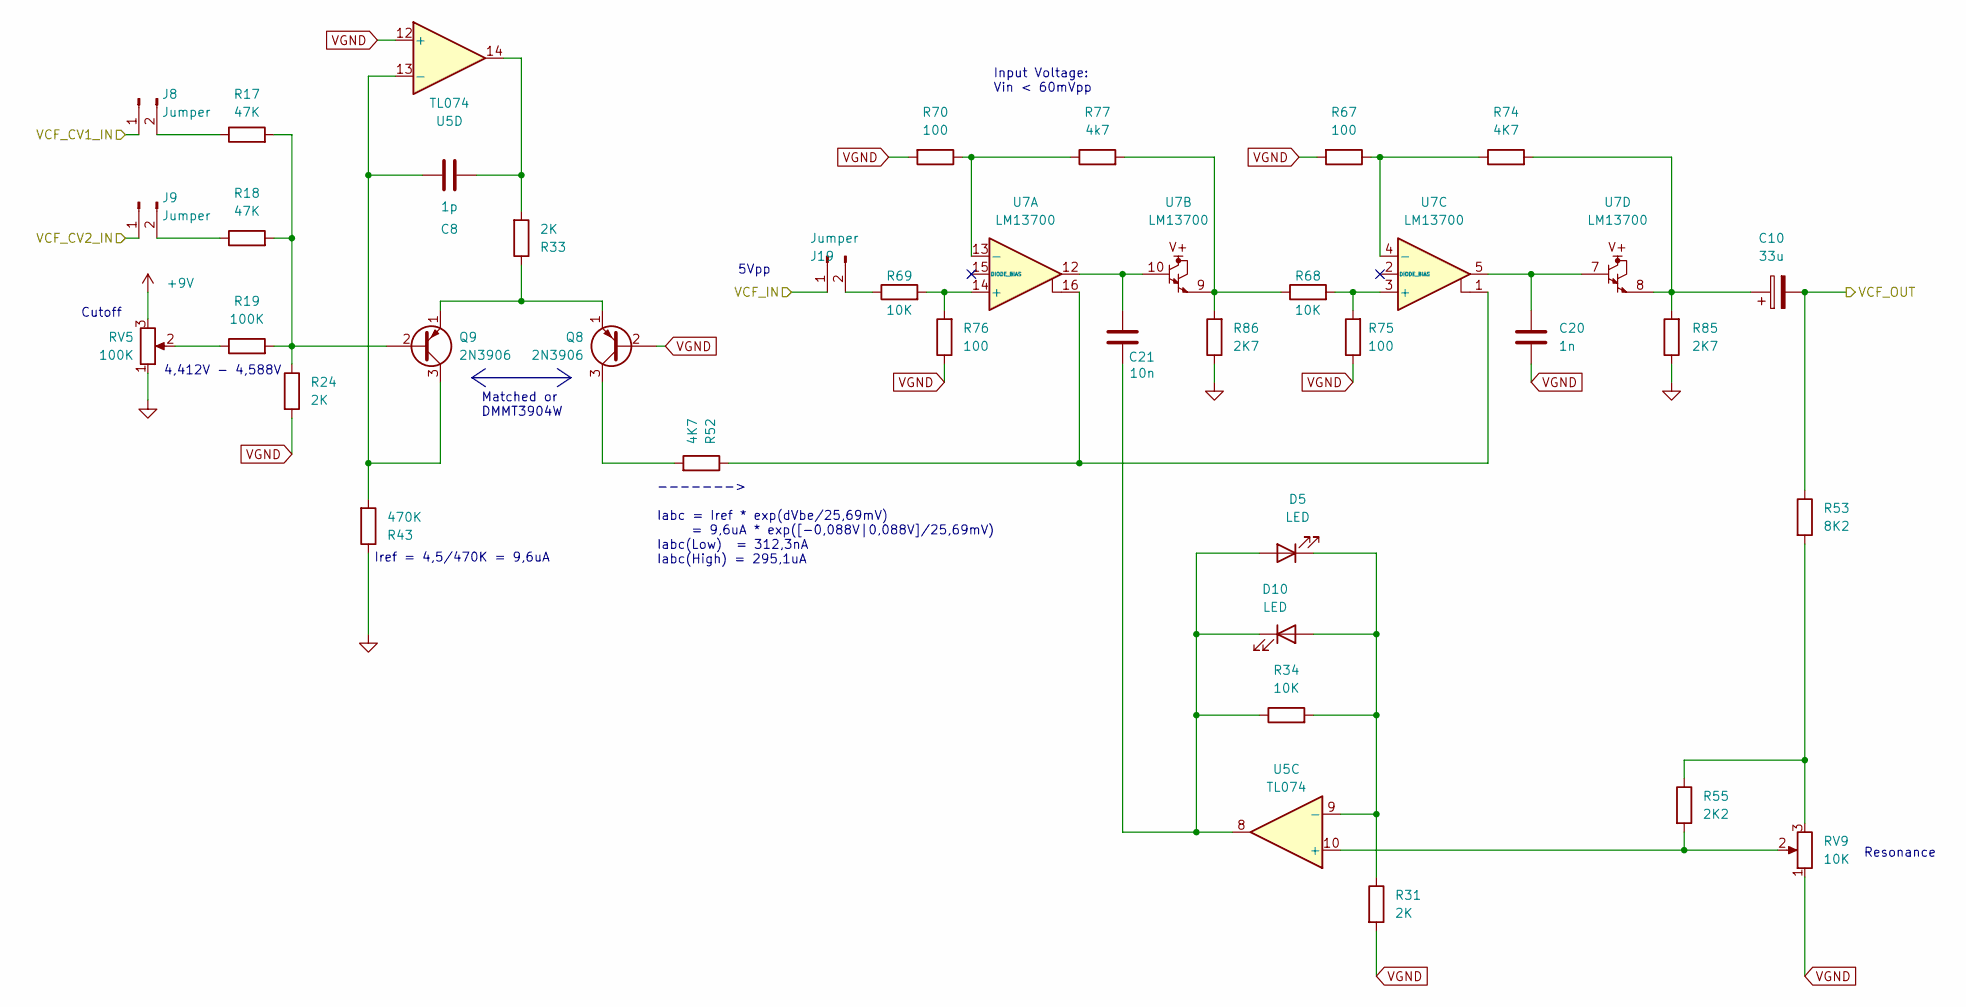
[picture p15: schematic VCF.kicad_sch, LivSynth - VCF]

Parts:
C8: 1p; C_Disc_D3.0mm_W1.6mm_P2.50mm
C10: 33u; CP_Radial_D8.0mm_P3.50mm
C20: 1n; C_Rect_L7.2mm_W2.5mm_P5.00mm_FKS2_FKP2_MKS2_MKP2
C21: 10n; C_Rect_L7.2mm_W2.5mm_P5.00mm_FKS2_FKP2_MKS2_MKP2
D5, D10: LED; LED_D5.0mm
J8, J9, J19: Jumper; PinHeader_1x02_P2.54mm_Vertical
Q8, Q9: 2N3906; TO-92_Inline
R17, R18: 47K; R_Axial_DIN0207_L6.3mm_D2.5mm_P7.62mm_Horizontal
R19: 100K; R_Axial_DIN0207_L6.3mm_D2.5mm_P7.62mm_Horizontal
R24, R31, R33: 2K; R_Axial_DIN0207_L6.3mm_D2.5mm_P7.62mm_Horizontal
R34, R68, R69: 10K; R_Axial_DIN0207_L6.3mm_D2.5mm_P7.62mm_Horizontal
R43: 470K; R_Axial_DIN0207_L6.3mm_D2.5mm_P7.62mm_Horizontal
R52, R74: 4K7; R_Axial_DIN0207_L6.3mm_D2.5mm_P7.62mm_Horizontal
R53: 8K2; R_Axial_DIN0207_L6.3mm_D2.5mm_P7.62mm_Horizontal
R55: 2K2; R_Axial_DIN0207_L6.3mm_D2.5mm_P7.62mm_Horizontal
R67, R70, R75, R76: 100; R_Axial_DIN0207_L6.3mm_D2.5mm_P7.62mm_Horizontal
R77: 4k7; R_Axial_DIN0207_L6.3mm_D2.5mm_P7.62mm_Horizontal
R85, R86: 2K7; R_Axial_DIN0207_L6.3mm_D2.5mm_P7.62mm_Horizontal
RV5: 100K; RV141F-40-20BL
RV9: 10K; RV141F-40-20BL
U5: TL074; SOIC-14_3.9x8.7mm_P1.27mm; LCSC C2057504
U7: LM13700; SOP-16_3.9x9.9mm_P1.27mm; LCSC C4370932

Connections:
+9V: RV5.3; also elsewhere on the board
/ModMatrix/VCF_EG_OUT: J9.1; also elsewhere on the board
/ModMatrix/VCF_LFO_OUT: J8.1; also elsewhere on the board
/VCA/VCA_IN: C10.2, R53.1; also elsewhere on the board
/VCF/VCF_IN: J19.1; also elsewhere on the board
GND: R43.1, R85.1, R86.1, RV5.1; also elsewhere on the board
unnamed: C8.2, R33.2, U5.14
unnamed: C10.1, R74.2, R85.2, U7.8
unnamed: C20.1, U7.5, U7.7
unnamed: C21.1, U7.10, U7.12
unnamed: D5.1 (K), D10.2 (A), R31.1, R34.2, U5.9 (-)
unnamed: C21.2, D5.2 (A), D10.1 (K), R34.1, U5.8
unnamed: J8.2, R17.1
unnamed: J9.2, R18.1
unnamed: J19.2, R69.1
unnamed: Q8.3 (C), R52.2
unnamed: Q8.1 (E), Q9.1 (E), R33.1
unnamed: Q9.2 (B), R17.2, R18.2, R19.2, R24.1
unnamed: C8.1, Q9.3 (C), R43.2, U5.13 (-)
unnamed: R19.1, RV5.2
unnamed: R52.1, U7.1, U7.16
unnamed: R53.2, R55.1, RV9.3
unnamed: R68.1, R77.2, R86.2, U7.9
unnamed: R55.2, RV9.2, U5.10 (+)
unnamed: R69.2, R76.2, U7.14 (+)
unnamed: R70.1, R77.1, U7.13 (-)
unnamed: R68.2, R75.2, U7.3 (+)
unnamed: R67.1, R74.1, U7.4 (-)
VGND: C20.2, Q8.2 (B), R24.2, R31.2, R67.2, R70.2, R75.1, R76.1, RV9.1, U5.12 (+); also elsewhere on the board

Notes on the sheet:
Iref = 4,5/470K = 9,6uA
5Vpp
4,412V - 4,588V
-------> Iabc = Iref * exp(dVbe/25,69mV) = 9,6uA * exp([-0,088V|0,088V]/25,69mV) Iabc(Low) = 312,3nA Iabc(High) = 295,1uA
Input Voltage: Vin < 60mVpp
Resonance
Cutoff
Matched or DMMT3904W

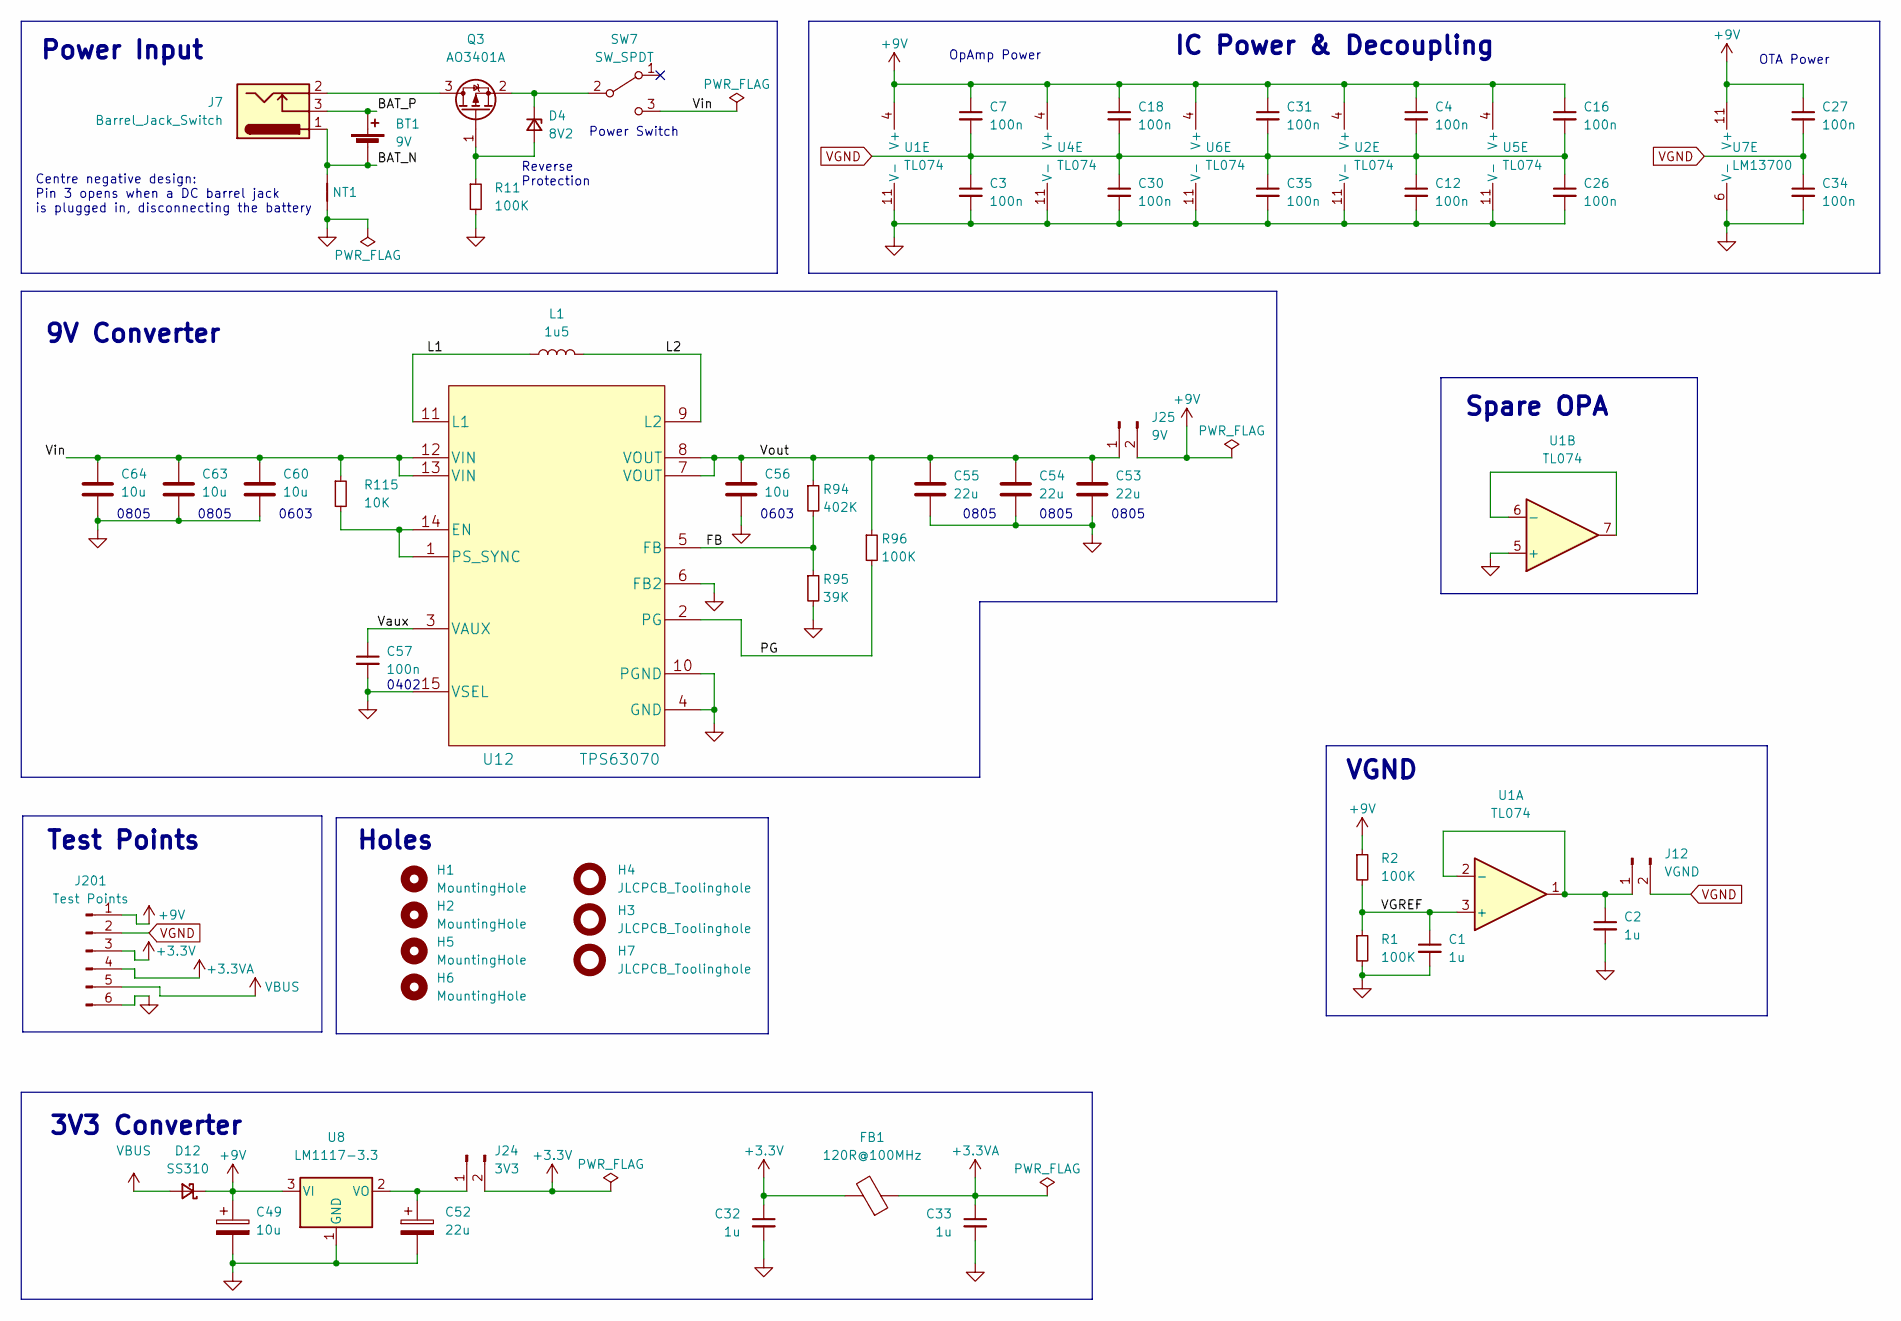
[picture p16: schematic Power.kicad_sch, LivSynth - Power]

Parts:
BT1: 9V; BatteryHolder_Eagle_12BH611-GR
C1, C2, C32, C33: 1u; C_Rect_L7.2mm_W5.5mm_P5.00mm_FKS2_FKP2_MKS2_MKP2
C3, C4, C7, C12, C16, C18, C26, C27, C30, C31, C34, C35: 100n; C_Rect_L7.2mm_W2.5mm_P5.00mm_FKS2_FKP2_MKS2_MKP2
C49: 10u; CP_Radial_D8.0mm_P3.50mm
C52: 22u; CP_Radial_D8.0mm_P3.50mm
C53, C54, C55: 22u; C_0805_2012Metric_Pad1.18x1.45mm_HandSolder; LCSC C415296
C56, C60: 10u; C_0603_1608Metric_Pad1.08x0.95mm_HandSolder; LCSC C96446
C57: 100n; C_0402_1005Metric_Pad0.74x0.62mm_HandSolder; LCSC C1523
C63, C64: 10u; C_0805_2012Metric_Pad1.18x1.45mm_HandSolder; LCSC C109040
D4: 8V2; D_SOD-123; LCSC C438308
D12: SS310; D_SMC_Handsoldering
FB1: 120R@100MHz; L_0603_1608Metric
H1, H2, H5, H6: MountingHole; MountingHole_3.2mm_M3
H3, H4, H7: JLCPCB_Toolinghole; JLCPCB_ToolingHole
J7: Barrel_Jack_Switch; BarrelJack_CUI_PJ-102AH_Horizontal
J12: VGND; PinHeader_1x02_P2.54mm_Vertical
J24: 3V3; PinHeader_1x02_P2.54mm_Vertical
J25: 9V; PinHeader_1x02_P2.54mm_Vertical
J201: Test Points; PinHeader_1x06_P2.54mm_Vertical
L1: 1u5; L_Sunlord_SWPA5020S; LCSC C279945
NT1: NetTie_2; NetTie-2_SMD_Pad0.5mm
Q3: AO3401A; SOT-23; LCSC C347476
R1, R2, R11: 100K; R_Axial_DIN0207_L6.3mm_D2.5mm_P7.62mm_Horizontal
R94: 402K; R_0603_1608Metric_Pad0.98x0.95mm_HandSolder; LCSC C844562
R95: 39K; R_0603_1608Metric_Pad0.98x0.95mm_HandSolder; LCSC C163424
R96: 100K; R_0603_1608Metric_Pad0.98x0.95mm_HandSolder; LCSC C25803
R115: 10K; R_0603_1608Metric_Pad0.98x0.95mm_HandSolder; LCSC C25804
SW7: SW_SPDT; SW_E-Switch_EG1224_SPDT_Angled
U1, U2, U4, U5, U6: TL074; SOIC-14_3.9x8.7mm_P1.27mm; LCSC C2057504
U7: LM13700; SOP-16_3.9x9.9mm_P1.27mm; LCSC C4370932
U8: LM1117-3.3; SOT-223-3_TabPin2; LCSC C126027
U12: TPS63070; TPS63070x; LCSC C109322

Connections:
+3.3V: C32.1, FB1.2, J24.2, J201.3; also elsewhere on the board
+3.3VA: C33.1, FB1.1, J201.4; also elsewhere on the board
+9V: C4.1, C7.1, C16.1, C18.1, C27.1, C31.1, C49.1, D12.1 (K), J25.2, J201.1, R2.1, U1.4 (V+), U2.4 (V+), U4.4 (V+), U5.4 (V+), U6.4 (V+), U7.11 (V+), U8.3 (VI); also elsewhere on the board
/Power/BAT_N: BT1.2 (-), J7.1, NT1.2
/Power/BAT_P: BT1.1 (+), J7.3
/Power/FB: R94.2, R95.1, U12.5 (FB)
/Power/L1: L1.1, U12.11 (L1)
/Power/L2: L1.2, U12.9 (L2)
/Power/PG: R96.2, U12.2 (PG)
/Power/VGREF: C1.1, R1.1, R2.2, U1.3 (+)
/Power/Vaux: C57.1, U12.3 (VAUX)
/Power/Vin: C60.1, C63.1, C64.1, R115.1, SW7.3 (C), U12.12 (VIN), U12.13 (VIN)
/Power/Vout: C53.1, C54.1, C55.1, C56.1, J25.1, R94.1, R96.1, U12.7 (VOUT), U12.8 (VOUT)
GND: C1.2, C2.2, C3.2, C12.2, C26.2, C30.2, C32.2, C33.2, C34.2, C35.2, C49.2, C52.2, C53.2, C54.2, C55.2, C56.2, C57.2, C60.2, C63.2, C64.2, J201.6, NT1.1, R1.2, R11.2, R95.2, U1.5 (+), U1.11 (V-), U2.11 (V-), U4.11 (V-), U5.11 (V-), U6.11 (V-), U7.6 (V-), U8.1 (GND), U12.4 (GND), U12.6 (FB2), U12.10 (PGND), U12.15 (VSEL); also elsewhere on the board
unnamed: D4.2 (A), Q3.1 (G), R11.1
unnamed: D4.1 (K), Q3.2 (S), SW7.2 (B)
unnamed: C2.1, J12.1, U1.1, U1.2 (-)
unnamed: C52.1, J24.1, U8.2 (VO)
unnamed: J7.2, Q3.3 (D)
unnamed: U1.6 (-), U1.7
unnamed: R115.2, U12.1 (PS_SYNC), U12.14 (EN)
VBUS: D12.2 (A), J201.5; also elsewhere on the board
VGND: C3.1, C4.2, C7.2, C12.1, C16.2, C18.2, C26.1, C27.2, C30.1, C31.2, C34.1, C35.1, J12.2, J201.2; also elsewhere on the board

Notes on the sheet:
9V Converter
0603
Centre negative design: Pin 3 opens when a DC barrel jack is plugged in, disconnecting the battery
0402
0805
Test Points
3V3 Converter
OTA Power
Power Switch
OpAmp Power
VGND
Spare OPA
IC Power & Decoupling
Reverse Protection
Holes
Power Input

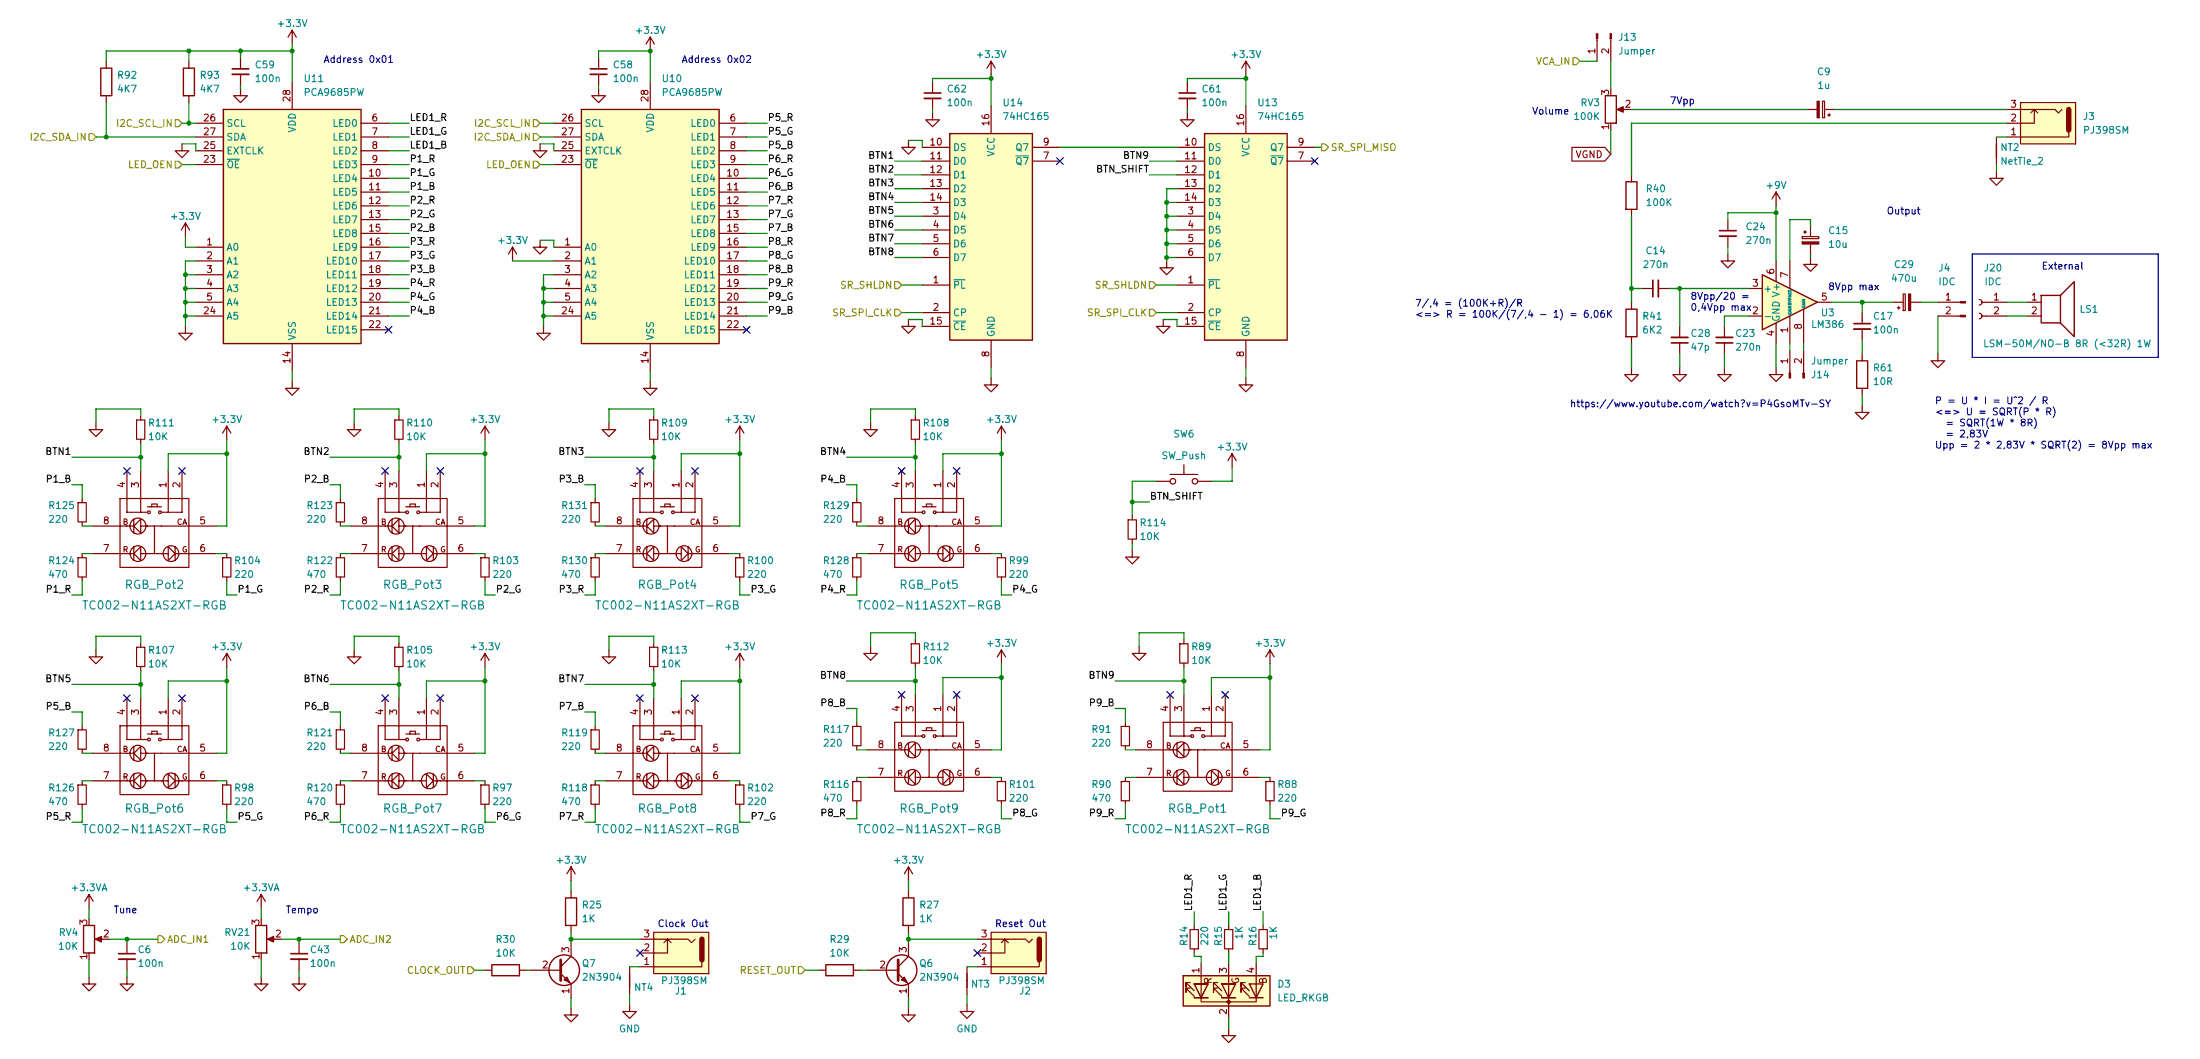
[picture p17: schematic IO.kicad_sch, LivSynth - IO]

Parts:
C6, C17, C43, C58, C59, C61, C62: 100n; C_Rect_L7.2mm_W2.5mm_P5.00mm_FKS2_FKP2_MKS2_MKP2
C9: 1u; C_Rect_L7.2mm_W5.5mm_P5.00mm_FKS2_FKP2_MKS2_MKP2
C14, C23, C24: 270n; C_Rect_L7.2mm_W4.5mm_P5.00mm_FKS2_FKP2_MKS2_MKP2
C15: 10u; CP_Radial_D8.0mm_P3.50mm
C28: 47p; C_Disc_D3.0mm_W1.6mm_P2.50mm
C29: 470u; CP_Radial_D8.0mm_P3.50mm
D3: LED_RKGB; LED_D5.0mm-4_RGB
J1, J2, J3: PJ398SM; Thonkiconn_PJ398SM
J4: IDC; PinHeader_1x02_P2.54mm_Vertical
J13, J14: Jumper; PinHeader_1x02_P2.54mm_Vertical
J20: IDC
LS1: LSM-50M/NO-B 8R (<32R) 1W; LSM-50M NO-B
NT2, NT3, NT4: NetTie_2; NetTie-2_SMD_Pad0.5mm
Q6, Q7: 2N3904; TO-92_Inline
R14, R88, R91, R97, R98, R99, R100, R101, R102, R103, R104, R117, R119, R121, R123, R125, R127, R129, R131: 220; R_Axial_DIN0207_L6.3mm_D2.5mm_P7.62mm_Horizontal
R15, R16, R25, R27: 1K; R_Axial_DIN0207_L6.3mm_D2.5mm_P7.62mm_Horizontal
R29, R30, R89, R105, R107, R108, R109, R110, R111, R112, R113, R114: 10K; R_Axial_DIN0207_L6.3mm_D2.5mm_P7.62mm_Horizontal
R40: 100K; R_Axial_DIN0207_L6.3mm_D2.5mm_P7.62mm_Horizontal
R41: 6K2; R_Axial_DIN0207_L6.3mm_D2.5mm_P7.62mm_Horizontal
R61: 10R; R_Axial_DIN0207_L6.3mm_D2.5mm_P7.62mm_Horizontal
R90, R116, R118, R120, R122, R124, R126, R128, R130: 470; R_Axial_DIN0207_L6.3mm_D2.5mm_P7.62mm_Horizontal
R92, R93: 4K7; R_Axial_DIN0207_L6.3mm_D2.5mm_P7.62mm_Horizontal
RGB_Pot1, RGB_Pot2, RGB_Pot3, RGB_Pot4, RGB_Pot5, RGB_Pot6, RGB_Pot7, RGB_Pot8, RGB_Pot9: TC002-N11AS2XT-RGB
RV3: 100K; Alpha_RD901F
RV4: 10K; RV141F-40-20BL
RV21: 10K; Alpha_RD901F
SW6: SW_Push; E-Switch_TL1105SP
U3: LM386; DIP-8_W7.62mm_Socket
U10, U11: PCA9685PW; TSSOP-28_4.4x9.7mm_P0.65mm; LCSC C2678753
U13, U14: 74HC165; SOIC-16_3.9x9.9mm_P1.27mm; LCSC C7334

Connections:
+3.3V: C58.1, C59.1, C61.1, C62.1, R25.1, R27.1, R92.1, R93.1, RGB_Pot1.1 (UP-A), RGB_Pot1.5 (CA), RGB_Pot2.1 (UP-A), RGB_Pot2.5 (CA), RGB_Pot3.1 (UP-A), RGB_Pot3.5 (CA), RGB_Pot4.1 (UP-A), RGB_Pot4.5 (CA), RGB_Pot5.1 (UP-A), RGB_Pot5.5 (CA), RGB_Pot6.1 (UP-A), RGB_Pot6.5 (CA), RGB_Pot7.1 (UP-A), RGB_Pot7.5 (CA), RGB_Pot8.1 (UP-A), RGB_Pot8.5 (CA), RGB_Pot9.1 (UP-A), RGB_Pot9.5 (CA), SW6.2, U10.2 (A1), U10.28 (VDD), U11.1 (A0), U11.28 (VDD), U13.16 (VCC), U14.16 (VCC); also elsewhere on the board
+3.3VA: RV4.3, RV21.3; also elsewhere on the board
+9V: C24.1, U3.6 (V+); also elsewhere on the board
/IO/ADC_IN1: C6.1, RV4.2; also elsewhere on the board
/IO/ADC_IN2: C43.1, RV21.2; also elsewhere on the board
/IO/BTN1: R111.2, RGB_Pot2.3 (DOWN-A), U14.11 (D0)
/IO/BTN2: R110.2, RGB_Pot3.3 (DOWN-A), U14.12 (D1)
/IO/BTN3: R109.2, RGB_Pot4.3 (DOWN-A), U14.13 (D2)
/IO/BTN4: R108.2, RGB_Pot5.3 (DOWN-A), U14.14 (D3)
/IO/BTN5: R107.2, RGB_Pot6.3 (DOWN-A), U14.3 (D4)
/IO/BTN6: R105.2, RGB_Pot7.3 (DOWN-A), U14.4 (D5)
/IO/BTN7: R113.2, RGB_Pot8.3 (DOWN-A), U14.5 (D6)
/IO/BTN8: R112.2, RGB_Pot9.3 (DOWN-A), U14.6 (D7)
/IO/BTN9: R89.2, RGB_Pot1.3 (DOWN-A), U13.11 (D0); also elsewhere on the board
/IO/BTN_SHIFT: R114.1, SW6.1, U13.12 (D1); also elsewhere on the board
/IO/CLOCK_OUT: R30.1; also elsewhere on the board
/IO/I2C_SCL_IN: R93.2, U10.26 (SCL), U11.26 (SCL); also elsewhere on the board
/IO/I2C_SDA_IN: R92.2, U10.27 (SDA), U11.27 (SDA); also elsewhere on the board
/IO/LED1_B: R16.2, U11.8 (LED2)
/IO/LED1_G: R15.2, U11.7 (LED1)
/IO/LED1_R: R14.2, U11.6 (LED0)
/IO/LED_OEN: U10.23 (~OE), U11.23 (~OE); also elsewhere on the board
/IO/P1_B: R125.1, U11.11 (LED5)
/IO/P1_G: R104.2, U11.10 (LED4)
/IO/P1_R: R124.2, U11.9 (LED3)
/IO/P2_B: R123.1, U11.15 (LED8)
/IO/P2_G: R103.2, U11.13 (LED7)
/IO/P2_R: R122.2, U11.12 (LED6)
/IO/P3_B: R131.1, U11.18 (LED11)
/IO/P3_G: R100.2, U11.17 (LED10)
/IO/P3_R: R130.2, U11.16 (LED9)
/IO/P4_B: R129.1, U11.21 (LED14)
/IO/P4_G: R99.2, U11.20 (LED13)
/IO/P4_R: R128.2, U11.19 (LED12)
/IO/P5_B: R127.1, U10.8 (LED2)
/IO/P5_G: R98.2, U10.7 (LED1); also elsewhere on the board
/IO/P5_R: R126.2, U10.6 (LED0)
/IO/P6_B: R121.1, U10.11 (LED5)
/IO/P6_G: R97.2, U10.10 (LED4)
/IO/P6_R: R120.2, U10.9 (LED3)
/IO/P7_B: R119.1, U10.15 (LED8)
/IO/P7_G: R102.2, U10.13 (LED7)
/IO/P7_R: R118.2, U10.12 (LED6)
/IO/P8_B: R117.1, U10.18 (LED11)
/IO/P8_G: R101.2, U10.17 (LED10)
/IO/P8_R: R116.2, U10.16 (LED9)
/IO/P9_B: R91.1, U10.21 (LED14)
/IO/P9_G: R88.2, U10.20 (LED13)
/IO/P9_R: R90.2, U10.19 (LED12)
/IO/RESET_OUT: R29.1; also elsewhere on the board
/IO/SR_SHLDN: U13.1 (~PL), U14.1 (~PL); also elsewhere on the board
/IO/SR_SPI_CLK: U13.2 (CP), U14.2 (CP); also elsewhere on the board
/IO/VCA_IN: J13.1; also elsewhere on the board
GND: C6.2, C15.2, C23.1, C24.2, C28.1, C43.2, C58.2, C59.2, C61.2, C62.2, D3.2 (K), J4.2, NT2.1, NT3.1, NT4.1, Q6.1 (E), Q7.1 (E), R41.2, R61.2, R89.1, R105.1, R107.1, R108.1, R109.1, R110.1, R111.1, R112.1, R113.1, R114.2, RV4.1, RV21.1, U3.4 (GND), U10.1 (A0), U10.3 (A2), U10.4 (A3), U10.5 (A4), U10.14 (VSS), U10.24 (A5), U10.25 (EXTCLK), U11.2 (A1), U11.3 (A2), U11.4 (A3), U11.5 (A4), U11.14 (VSS), U11.24 (A5), U11.25 (EXTCLK), U13.3 (D4), U13.4 (D5), U13.5 (D6), U13.6 (D7), U13.8 (GND), U13.13 (D2), U13.14 (D3), U13.15 (~CE), U14.8 (GND), U14.10 (DS), U14.15 (~CE); also elsewhere on the board
unnamed: C9.1, J3.3
unnamed: C9.2, RV3.2
unnamed: C14.1, R40.2, R41.1
unnamed: C17.1, C29.1, U3.5
unnamed: C17.2, R61.1
unnamed: D3.4 (BA), R16.1
unnamed: D3.3 (GA), R15.1
unnamed: D3.1 (RA), R14.1
unnamed: J1.1, NT4.2
unnamed: J2.1, NT3.2
unnamed: J3.1, NT2.2
unnamed: J3.2, R40.1
unnamed: C29.2, J4.1
unnamed: J13.2, RV3.3
unnamed: J14.1, U3.1 (GAIN)
unnamed: J14.2, U3.8 (GAIN)
unnamed: J20.1, LS1.1
unnamed: J20.2, LS1.2
unnamed: Q6.2 (B), R29.2
unnamed: J2.3, Q6.3 (C), R27.2
unnamed: Q7.2 (B), R30.2
unnamed: J1.3, Q7.3 (C), R25.2
unnamed: R91.2, RGB_Pot1.8 (B)
unnamed: R88.1, RGB_Pot1.6 (G)
unnamed: R90.1, RGB_Pot1.7 (R)
unnamed: R125.2, RGB_Pot2.8 (B)
unnamed: R104.1, RGB_Pot2.6 (G)
unnamed: R124.1, RGB_Pot2.7 (R)
unnamed: R123.2, RGB_Pot3.8 (B)
unnamed: R103.1, RGB_Pot3.6 (G)
unnamed: R122.1, RGB_Pot3.7 (R)
unnamed: R131.2, RGB_Pot4.8 (B)
unnamed: R100.1, RGB_Pot4.6 (G)
unnamed: R130.1, RGB_Pot4.7 (R)
unnamed: R129.2, RGB_Pot5.8 (B)
unnamed: R99.1, RGB_Pot5.6 (G)
unnamed: R128.1, RGB_Pot5.7 (R)
unnamed: R127.2, RGB_Pot6.8 (B)
unnamed 208: R98.1, RGB_Pot6.6 (G); also elsewhere on the board
unnamed: R126.1, RGB_Pot6.7 (R)
unnamed: R121.2, RGB_Pot7.8 (B)
unnamed: R97.1, RGB_Pot7.6 (G)
unnamed: R120.1, RGB_Pot7.7 (R)
unnamed: R119.2, RGB_Pot8.8 (B)
unnamed: R102.1, RGB_Pot8.6 (G)
unnamed: R118.1, RGB_Pot8.7 (R)
unnamed: R117.2, RGB_Pot9.8 (B)
unnamed: R101.1, RGB_Pot9.6 (G)
unnamed: R116.1, RGB_Pot9.7 (R)
unnamed: C14.2, C28.2, U3.3 (+)
unnamed: C23.2, U3.2 (-)
unnamed: C15.1, U3.7 (BYPASS)
unnamed 253: U13.10 (DS), U14.9 (Q7); also elsewhere on the board
VGND: RV3.1; also elsewhere on the board

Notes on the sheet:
Address 0x01
Clock Out
8Vpp/20 = 0,4Vpp max
https://www.youtube.com/watch?v=P4GsoMTv-SY
Tempo
Tune
Output
7/,4 = (100K+R)/R <=> R = 100K/(7/,4 - 1) = 6,06K
Address 0x02
Volume
Reset Out
External
8Vpp max
P = U * I = U^2 / R <=> U = SQRT(P * R) = SQRT(1W * 8R) = 2,83V Upp = 2 * 2,83V * SQRT(2) = 8Vpp max
7Vpp

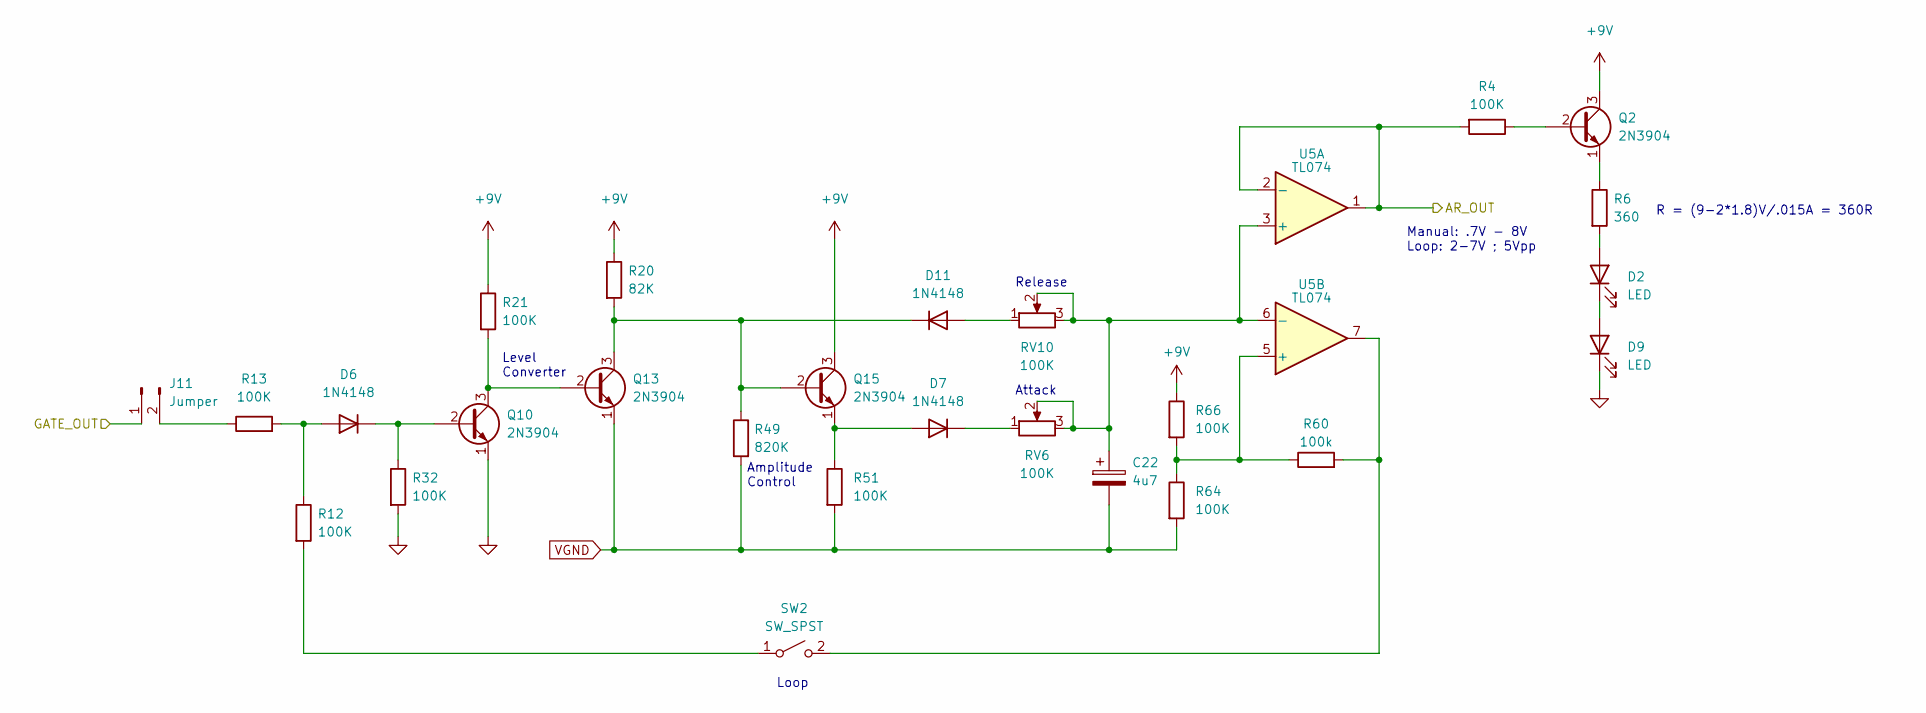
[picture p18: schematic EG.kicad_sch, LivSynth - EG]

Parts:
C22: 4u7; CP_Radial_D8.0mm_P3.50mm
D2, D9: LED; LED_D5.0mm
D6, D7, D11: 1N4148; D_DO-35_SOD27_P7.62mm_Horizontal
J11: Jumper; PinHeader_1x02_P2.54mm_Vertical
Q2, Q10, Q13, Q15: 2N3904; TO-92_Inline
R4, R12, R13, R21, R32, R51, R64, R66: 100K; R_Axial_DIN0207_L6.3mm_D2.5mm_P7.62mm_Horizontal
R6: 360; R_Axial_DIN0207_L6.3mm_D2.5mm_P7.62mm_Horizontal
R20: 82K; R_Axial_DIN0207_L6.3mm_D2.5mm_P7.62mm_Horizontal
R49: 820K; R_Axial_DIN0207_L6.3mm_D2.5mm_P7.62mm_Horizontal
R60: 100k; R_Axial_DIN0207_L6.3mm_D2.5mm_P7.62mm_Horizontal
RV6, RV10: 100K; RV141F-40-20BL
SW2: SW_SPST; SW_Toggle_MS500
U5: TL074; SOIC-14_3.9x8.7mm_P1.27mm; LCSC C2057504

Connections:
+9V: Q2.3 (C), Q15.3 (C), R20.1, R21.1, R66.1; also elsewhere on the board
/EG/AR_OUT: R4.2, U5.1, U5.2 (-); also elsewhere on the board
/EG/GATE_OUT: J11.1; also elsewhere on the board
GND: D9.1 (K), Q10.1 (E), R32.2; also elsewhere on the board
unnamed: D2.2 (A), R6.2
unnamed: D2.1 (K), D9.2 (A)
unnamed: D6.2 (A), R12.1, R13.2
unnamed: D6.1 (K), Q10.2 (B), R32.1
unnamed: D7.2 (A), Q15.1 (E), R51.1
unnamed: D7.1 (K), RV6.1
unnamed: D11.2 (A), RV10.1
unnamed: D11.1 (K), Q13.3 (C), Q15.2 (B), R20.2, R49.1
unnamed: J11.2, R13.1
unnamed: Q2.2 (B), R4.1
unnamed: Q2.1 (E), R6.1
unnamed: Q10.3 (C), Q13.2 (B), R21.2
unnamed: R12.2, SW2.1 (A)
unnamed: R60.2, SW2.2 (B), U5.7
unnamed: C22.1, RV6.2, RV6.3, RV10.2, RV10.3, U5.3 (+), U5.6 (-)
unnamed: R60.1, R64.1, R66.2, U5.5 (+)
VGND: C22.2, Q13.1 (E), R49.2, R51.2, R64.2; also elsewhere on the board

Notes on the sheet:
R = (9-2*1.8)V/.015A = 360R
Attack
Amplitude Control
Release
Loop
Level Converter
Manual: .7V - 8V Loop: 2-7V ; 5Vpp

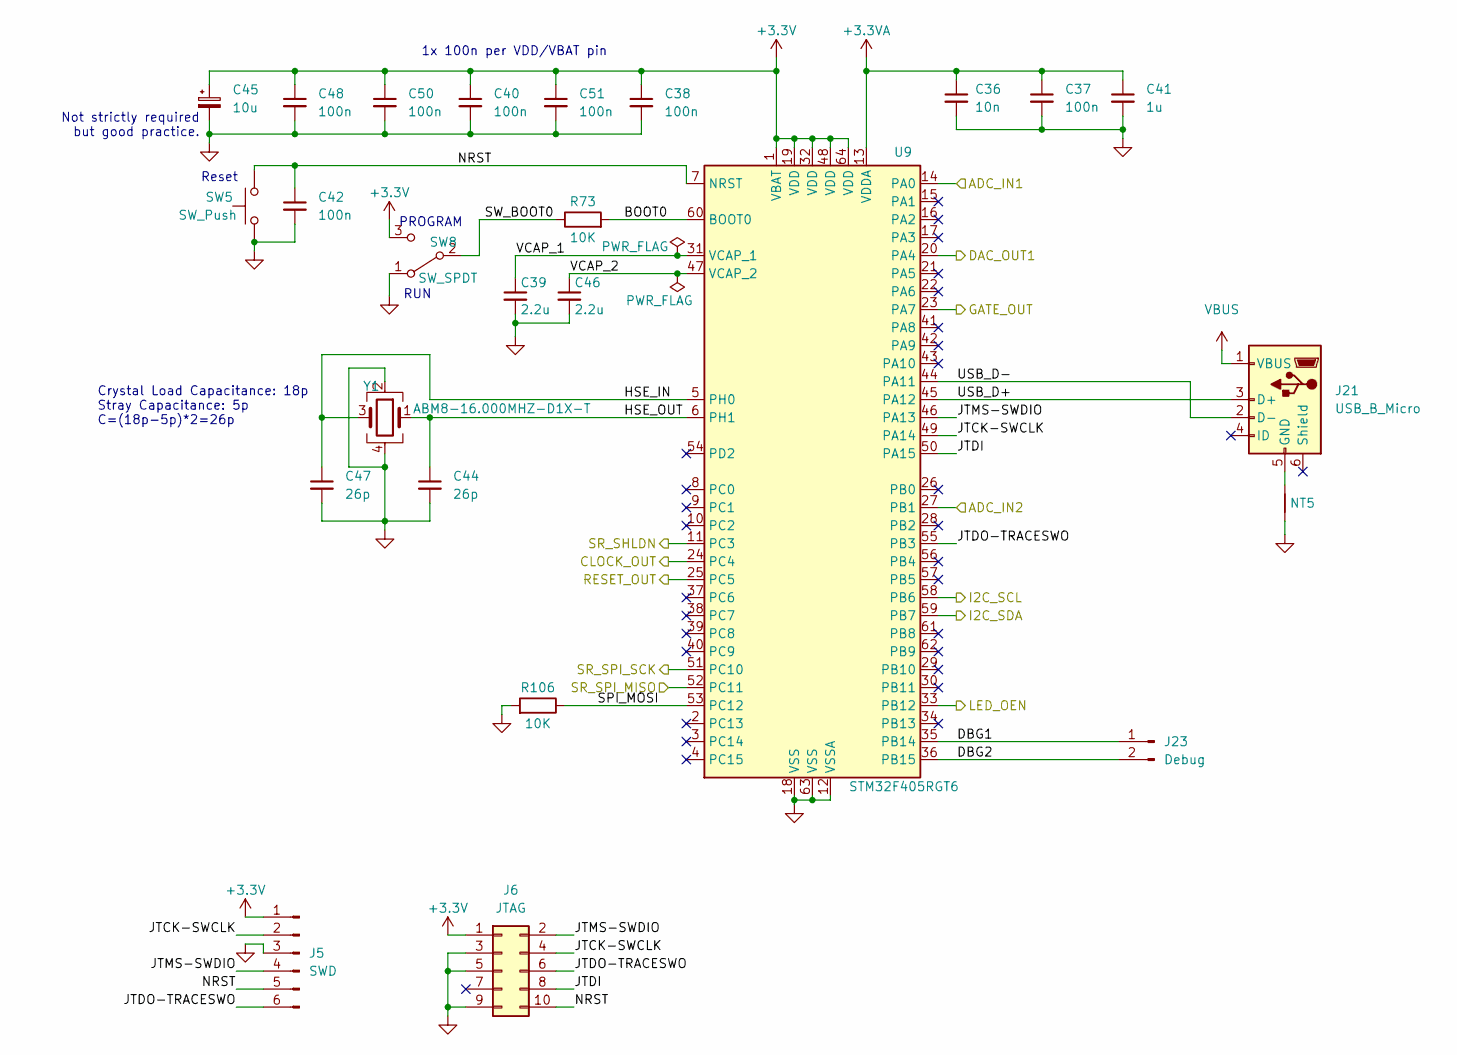
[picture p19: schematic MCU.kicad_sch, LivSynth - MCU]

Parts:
C36: 10n; C_Rect_L7.2mm_W2.5mm_P5.00mm_FKS2_FKP2_MKS2_MKP2
C37: 100n; C_Rect_L7.2mm_W2.5mm_P5.00mm_FKS2_FKP2_MKS2_MKP2
C38, C40, C42, C48, C50, C51: 100n; C_0603_1608Metric_Pad1.08x0.95mm_HandSolder; LCSC C282518
C39, C46: 2.2u; C_0603_1608Metric_Pad1.08x0.95mm_HandSolder; LCSC C268016
C41: 1u; C_Rect_L7.2mm_W5.5mm_P5.00mm_FKS2_FKP2_MKS2_MKP2
C44, C47: 26p; C_0603_1608Metric_Pad1.08x0.95mm_HandSolder; LCSC C519484
C45: 10u; CP_Radial_D8.0mm_P3.50mm
J5: SWD; PinHeader_1x06_P2.54mm_Vertical
J6: JTAG; PinHeader_2x05_P1.27mm_Vertical
J21: USB_B_Micro; USB_Micro-B_Wuerth_629105150521
J23: Debug; PinHeader_1x02_P2.54mm_Vertical
NT5: NetTie_2; NetTie-2_SMD_Pad0.5mm
R73, R106: 10K; R_Axial_DIN0207_L6.3mm_D2.5mm_P7.62mm_Horizontal
SW5: SW_Push; SW_SPST_EVQQ2
SW8: SW_SPDT; SW_E-Switch_EG1224_SPDT_Angled
U9: STM32F405RGT6; LQFP-64_10x10mm_P0.5mm; LCSC C15742
Y1: ABM8-16.000MHZ-D1X-T; Crystal_SMD_3225-4Pin_3.2x2.5mm_HandSoldering; LCSC C1985300

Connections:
+3.3V: C38.1, C40.1, C45.1, C48.1, C50.1, C51.1, J5.1, J6.1, SW8.3 (C), U9.1 (VBAT), U9.19 (VDD), U9.32 (VDD), U9.48 (VDD), U9.64 (VDD); also elsewhere on the board
+3.3VA: C36.1, C37.1, C41.1, U9.13 (VDDA); also elsewhere on the board
/EG/GATE_OUT: U9.23 (PA7); also elsewhere on the board
/IO/ADC_IN1: U9.14 (PA0); also elsewhere on the board
/IO/ADC_IN2: U9.27 (PB1); also elsewhere on the board
/IO/CLOCK_OUT: U9.24 (PC4); also elsewhere on the board
/IO/I2C_SCL_IN: U9.58 (PB6); also elsewhere on the board
/IO/I2C_SDA_IN: U9.59 (PB7); also elsewhere on the board
/IO/LED_OEN: U9.33 (PB12); also elsewhere on the board
/IO/RESET_OUT: U9.25 (PC5); also elsewhere on the board
/IO/SR_SHLDN: U9.11 (PC3); also elsewhere on the board
/IO/SR_SPI_CLK: U9.51 (PC10); also elsewhere on the board
/IO/SR_SPI_MISO: U9.52 (PC11); also elsewhere on the board
/MCU/BOOT0: R73.2, U9.60 (BOOT0)
/MCU/DAC_OUT1: U9.20 (PA4); also elsewhere on the board
/MCU/DBG1: J23.1, U9.35 (PB14)
/MCU/DBG2: J23.2, U9.36 (PB15)
/MCU/HSE_IN: C47.1, U9.5 (PH0), Y1.3
/MCU/HSE_OUT: C44.1, U9.6 (PH1), Y1.1
/MCU/JTCK-SWCLK: J5.2, J6.4, U9.49 (PA14)
/MCU/JTDI: J6.8, U9.50 (PA15)
/MCU/JTDO-TRACESWO: J5.6, J6.6, U9.55 (PB3)
/MCU/JTMS-SWDIO: J5.4, J6.2, U9.46 (PA13)
/MCU/NRST: C42.1, J5.5, J6.10, SW5.2, U9.7 (NRST)
/MCU/SPI_MOSI: R106.1, U9.53 (PC12)
/MCU/SW_BOOT0: R73.1, SW8.2 (B)
/MCU/USB_D+: J21.3 (D+), U9.45 (PA12)
/MCU/USB_D-: J21.2 (D-), U9.44 (PA11)
/MCU/VCAP_1: C39.1, U9.31 (VCAP_1)
/MCU/VCAP_2: C46.1, U9.47 (VCAP_2)
GND: C36.2, C37.2, C38.2, C39.2, C40.2, C41.2, C42.2, C44.2, C45.2, C46.2, C47.2, C48.2, C50.2, C51.2, J5.3, J6.3, J6.5, J6.9, NT5.1, R106.2, SW5.1, SW8.1 (A), U9.12 (VSSA), U9.18 (VSS), U9.63 (VSS), Y1.2, Y1.4; also elsewhere on the board
unnamed: J21.5 (GND), NT5.2
VBUS: J21.1 (VBUS); also elsewhere on the board

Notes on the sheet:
Not strictly required but good practice.
RUN
Crystal Load Capacitance: 18p Stray Capacitance: 5p C=(18p-5p)*2=26p
PROGRAM
1x 100n per VDD/VBAT pin
Reset

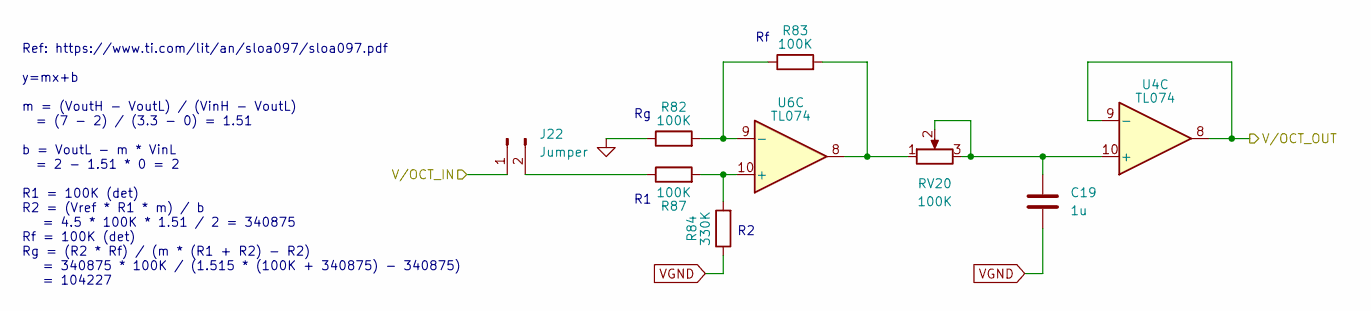
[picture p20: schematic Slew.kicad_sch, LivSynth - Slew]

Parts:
C19: 1u; C_Rect_L7.2mm_W5.5mm_P5.00mm_FKS2_FKP2_MKS2_MKP2
J22: Jumper; PinHeader_1x02_P2.54mm_Vertical
R82, R83, R87: 100K; R_Axial_DIN0207_L6.3mm_D2.5mm_P7.62mm_Horizontal
R84: 330K; R_Axial_DIN0207_L6.3mm_D2.5mm_P7.62mm_Horizontal
RV20: 100K; Alpha_RD901F
U4, U6: TL074; SOIC-14_3.9x8.7mm_P1.27mm; LCSC C2057504

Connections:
/MCU/DAC_OUT1: J22.1; also elsewhere on the board
/Slew/V/OCT_OUT: U4.8, U4.9 (-); also elsewhere on the board
GND: R82.1; also elsewhere on the board
unnamed: J22.2, R87.1
unnamed: R83.2, RV20.1, U6.8
unnamed: C19.1, RV20.2, RV20.3, U4.10 (+)
unnamed: R84.2, R87.2, U6.10 (+)
unnamed: R82.2, R83.1, U6.9 (-)
VGND: C19.2, R84.1; also elsewhere on the board

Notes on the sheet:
Ref: https://www.ti.com/lit/an/sloa097/sloa097.pdf y=mx+b m = (VoutH - VoutL) / (VinH - VoutL) = (7 - 2) / (3.3 - 0) = 1.51 b = VoutL - m * VinL = 2 - 1.51 * 0 = 2 R1 = 100K (det) R2 = (Vref * R1 * m) / b = 4.5 * 100K * 1.51 / 2 = 340875 Rf = 100K (det) Rg = (R2 * Rf) / (m * (R1 + R2) - R2) = 34087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

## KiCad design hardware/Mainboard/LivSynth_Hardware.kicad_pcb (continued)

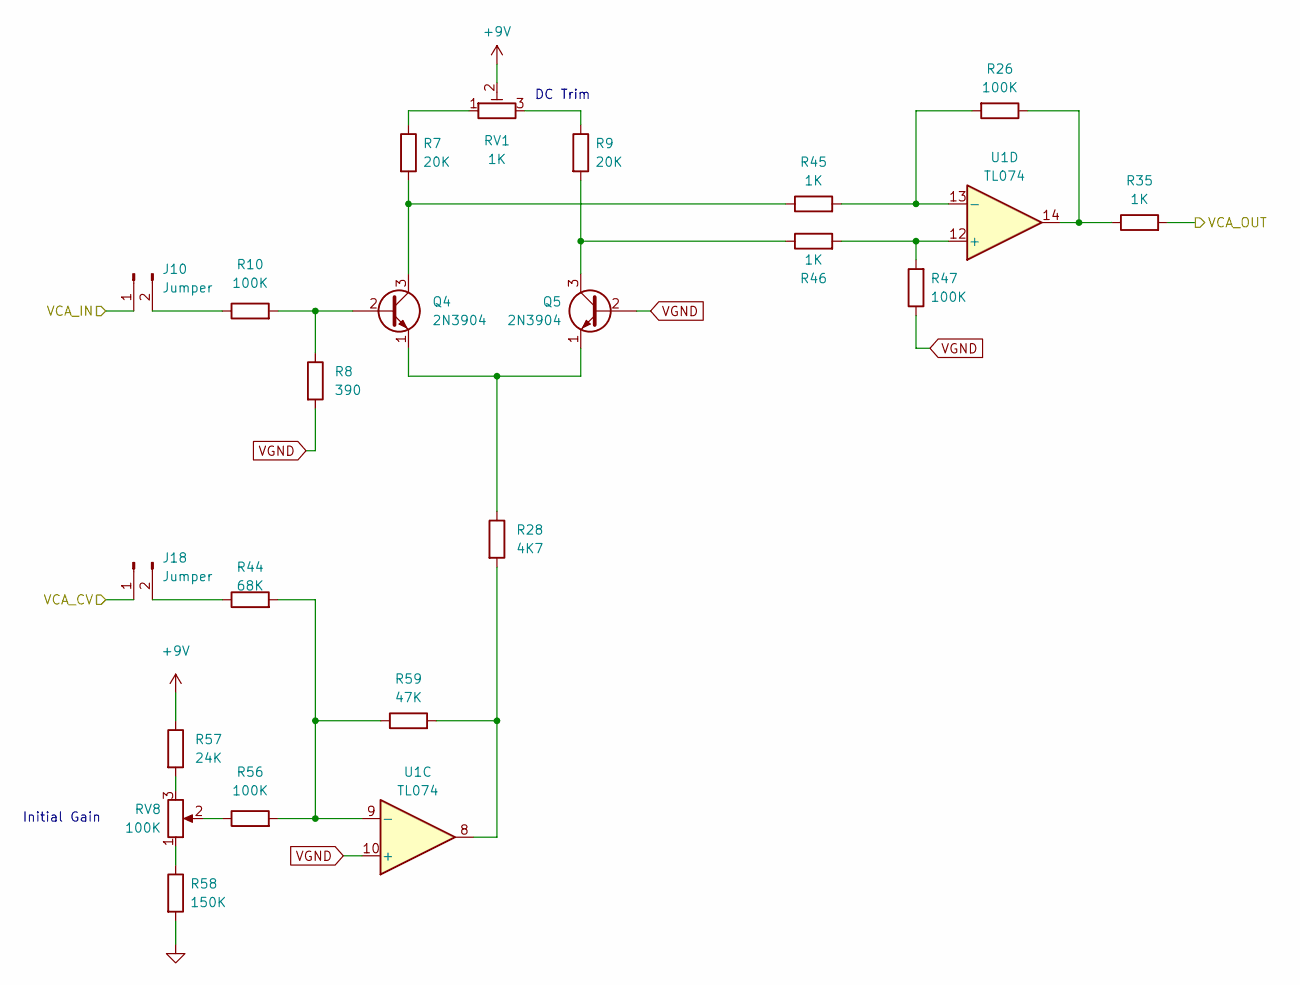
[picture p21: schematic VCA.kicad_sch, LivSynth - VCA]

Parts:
J10, J18: Jumper; PinHeader_1x02_P2.54mm_Vertical
Q4, Q5: 2N3904; TO-92_Inline
R7, R9: 20K; R_Axial_DIN0207_L6.3mm_D2.5mm_P7.62mm_Horizontal
R8: 390; R_Axial_DIN0207_L6.3mm_D2.5mm_P7.62mm_Horizontal
R10, R26, R47, R56: 100K; R_Axial_DIN0207_L6.3mm_D2.5mm_P7.62mm_Horizontal
R28: 4K7; R_Axial_DIN0207_L6.3mm_D2.5mm_P7.62mm_Horizontal
R35, R45, R46: 1K; R_Axial_DIN0207_L6.3mm_D2.5mm_P7.62mm_Horizontal
R44: 68K; R_Axial_DIN0207_L6.3mm_D2.5mm_P7.62mm_Horizontal
R57: 24K; R_Axial_DIN0207_L6.3mm_D2.5mm_P7.62mm_Horizontal
R58: 150K; R_Axial_DIN0207_L6.3mm_D2.5mm_P7.62mm_Horizontal
R59: 47K; R_Axial_DIN0207_L6.3mm_D2.5mm_P7.62mm_Horizontal
RV1: 1K; Potentiometer_Bourns_3296W_Vertical
RV8: 100K; Alpha_RD901F
U1: TL074; SOIC-14_3.9x8.7mm_P1.27mm; LCSC C2057504

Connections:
+9V: R57.1, RV1.2; also elsewhere on the board
/IO/VCA_IN: R35.2; also elsewhere on the board
/ModMatrix/VCA_CV_OUT: J18.1; also elsewhere on the board
/VCA/VCA_IN: J10.1; also elsewhere on the board
GND: R58.2; also elsewhere on the board
unnamed: J10.2, R10.1
unnamed: J18.2, R44.1
unnamed: Q4.2 (B), R8.1, R10.2
unnamed: Q4.3 (C), R7.2, R45.1
unnamed: Q4.1 (E), Q5.1 (E), R28.1
unnamed: Q5.3 (C), R9.2, R46.1
unnamed: R7.1, RV1.1
unnamed: R9.1, RV1.3
unnamed: R26.1, R35.1, U1.14
unnamed: R28.2, R59.2, U1.8
unnamed: R56.1, RV8.2
unnamed: R57.2, RV8.3
unnamed: R58.1, RV8.1
unnamed: R44.2, R56.2, R59.1, U1.9 (-)
unnamed: R46.2, R47.2, U1.12 (+)
unnamed: R26.2, R45.2, U1.13 (-)
VGND: Q5.2 (B), R8.2, R47.1, U1.10 (+); also elsewhere on the board

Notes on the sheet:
DC Trim
Initial Gain

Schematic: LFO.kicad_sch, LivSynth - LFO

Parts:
C25: 270n; C_Rect_L7.2mm_W5.5mm_P5.00mm_FKS2_FKP2_MKS2_MKP2
D1, D8: LED; LED_D5.0mm
Q1, Q16, Q17: 2N3904; TO-92_Inline
R3, R72: 100K; R_Axial_DIN0207_L6.3mm_D2.5mm_P7.62mm_Horizontal
R5: 360; R_Axial_DIN0207_L6.3mm_D2.5mm_P7.62mm_Horizontal
R42, R54: 2K; R_Axial_DIN0207_L6.3mm_D2.5mm_P7.62mm_Horizontal
R50: 100R; R_Axial_DIN0207_L6.3mm_D2.5mm_P7.62mm_Horizontal
R62, R63: 1M; R_Axial_DIN0207_L6.3mm_D2.5mm_P7.62mm_Horizontal
R71: 68k; R_Axial_DIN0207_L6.3mm_D2.5mm_P7.62mm_Horizontal
RV7, RV11: 100K; RV141F-40-20BL
U6: TL074; SOIC-14_3.9x8.7mm_P1.27mm; LCSC C2057504

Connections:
+9V: R5.1; also elsewhere on the board
/LFO/LFO_SQA_OUT: R3.2, R63.2, U6.1; also elsewhere on the board
/LFO/LFO_TRI_OUT: C25.2, R71.1, U6.7; also elsewhere on the board
GND: D8.1 (K); also elsewhere on the board
unnamed: D1.2 (A), Q1.1 (E)
unnamed: D1.1 (K), D8.2 (A)
unnamed: Q1.2 (B), R3.1
unnamed: Q1.3 (C), R5.2
unnamed: Q16.2 (B), R62.1
unnamed: Q16.3 (C), Q17.1 (E), R50.2
unnamed: Q16.1 (E), RV11.3
unnamed: Q17.2 (B), R63.1
unnamed: Q17.3 (C), RV11.1
unnamed: R42.2, RV7.3
unnamed: R50.1, RV7.2
unnamed: R54.1, RV7.1
unnamed: R42.1, R62.2, R72.2, U6.2 (-), U6.14
unnamed: C25.1, RV11.2, U6.6 (-)
unnamed: R71.2, R72.1, U6.12 (+)
VGND: R54.2, U6.3 (+), U6.5 (+), U6.13 (-); also elsewhere on the board

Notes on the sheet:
LFO Shape
LFO Rate
Fast Slow
R = (9-2*1.8)V/.015A = 360R
Value significant for performance: big enough to ramp up small enough for slow rates

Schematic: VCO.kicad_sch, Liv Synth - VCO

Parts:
C5: 1n; C_Rect_L7.2mm_W2.5mm_P5.00mm_FKS2_FKP2_MKS2_MKP2
C11: 1p; C_Disc_D3.0mm_W1.6mm_P2.50mm
C13: 10n; C_Rect_L7.2mm_W2.5mm_P5.00mm_FKS2_FKP2_MKS2_MKP2
J15, J16, J17: Jumper; PinHeader_1x02_P2.54mm_Vertical
Q11, Q12, Q14: 2N3904; TO-92_Inline
R22, R37, R38, R39: 100K; R_Axial_DIN0207_L6.3mm_D2.5mm_P7.62mm_Horizontal
R23: 470K; R_Axial_DIN0207_L6.3mm_D2.5mm_P7.62mm_Horizontal
R36: 2K; R_Axial_DIN0207_L6.3mm_D2.5mm_P7.62mm_Horizontal
R48: 1K; R_Axial_DIN0207_L6.3mm_D2.5mm_P7.62mm_Horizontal
R65: 390; R_Axial_DIN0207_L6.3mm_D2.5mm_P7.62mm_Horizontal
RV2, RV15, RV16, RV17: 100K; Potentiometer_Bourns_3296W_Vertical
RV12: 100; Potentiometer_Bourns_3296W_Vertical
SW1: SW_SPDT; SW_Toggle_MS500
TH1: 2K 3300ppm LT16S202F33; R_Axial_DIN0207_L6.3mm_D2.5mm_P7.62mm_Horizontal
U2, U4: TL074; SOIC-14_3.9x8.7mm_P1.27mm; LCSC C2057504

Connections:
+9V: R23.1, RV2.3, RV16.3; also elsewhere on the board
/ModMatrix/VCO_EG_OUT: J17.1; also elsewhere on the board
/ModMatrix/VCO_LFO_OUT: J16.1; also elsewhere on the board
/Slew/V/OCT_OUT: J15.1; also elsewhere on the board
/VCF/VCF_IN: SW1.2 (B); also elsewhere on the board
/VCO/SAW_OUT: C13.2, R48.2, RV15.1, SW1.1 (A), U2.7, U4.13 (-)
/VCO/SQUARE_OUT: RV17.2, SW1.3 (C)
GND: RV2.1; also elsewhere on the board
unnamed: C11.2, R36.2, U2.8
unnamed: J15.2, R37.1
unnamed: J16.2, R38.1
unnamed: J17.2, R39.1
unnamed: C13.1, Q11.3 (C), Q14.1 (E), U2.6 (-)
unnamed: Q11.1 (E), Q12.1 (E), R36.1
unnamed: Q12.2 (B), RV12.2
unnamed: C11.1, Q12.3 (C), R23.2, U2.9 (-)
unnamed: C5.2, Q14.2 (B), U2.14
unnamed: Q14.3 (C), R48.1
unnamed: R22.1, RV2.2
unnamed: R65.1, RV12.1
unnamed: RV12.3, TH1.2, U2.1
unnamed: RV17.3, U4.14
unnamed: R22.2, R37.2, R38.2, R39.2, TH1.1, U2.2 (-)
unnamed: C5.1, RV15.2, RV15.3, U2.12 (+)
unnamed: RV16.2, U2.13 (-)
VGND: Q11.2 (B), R65.2, RV16.1, RV17.1, U2.3 (+), U2.5 (+), U2.10 (+), U4.12 (+); also elsewhere on the board

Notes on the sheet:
f(dVbe = 0) = 9,6uA / (10nF * 5Vpp) -> 192Hz
WF Sel
SAW discharge time
Iref = 4,5V/470K -> 9,6uA
Tracking
Matched or DMMT3904W
SQUARE amplitude
Thermal Coupling
Fine Tune
SAW vertical offset

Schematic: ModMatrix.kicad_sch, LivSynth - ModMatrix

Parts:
R78, R79, R80, R81: 100K; R_Axial_DIN0207_L6.3mm_D2.5mm_P7.62mm_Horizontal
RV13, RV14, RV18, RV19, RV22: 100K; Alpha_RD901F
SW3, SW4: SW_SPDT; SW_Toggle_MS500
U4: TL074; SOIC-14_3.9x8.7mm_P1.27mm; LCSC C2057504

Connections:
/EG/AR_OUT: R79.1, R81.1, RV13.3, RV14.3, SW4.1 (A); also elsewhere on the board
/LFO/LFO_SQA_OUT: SW3.1 (A); also elsewhere on the board
/LFO/LFO_TRI_OUT: SW3.3 (C); also elsewhere on the board
/ModMatrix/VCA_CV_OUT: RV22.2; also elsewhere on the board
/ModMatrix/VCF_EG_OUT: R78.2, U4.1; also elsewhere on the board
/ModMatrix/VCF_LFO_OUT: RV19.2; also elsewhere on the board
/ModMatrix/VCO_EG_OUT: R80.2, U4.7; also elsewhere on the board
/ModMatrix/VCO_LFO_OUT: RV18.2; also elsewhere on the board
unnamed: RV18.3, RV19.3, SW3.2 (B), SW4.3 (C)
unnamed: RV22.3, SW4.2 (B)
unnamed: RV14.2, U4.3 (+)
unnamed: R78.1, R79.2, U4.2 (-)
unnamed: RV13.2, U4.5 (+)
unnamed: R80.1, R81.2, U4.6 (-)
VGND: RV13.1, RV14.1, RV18.1, RV19.1, RV22.1; also elsewhere on the board

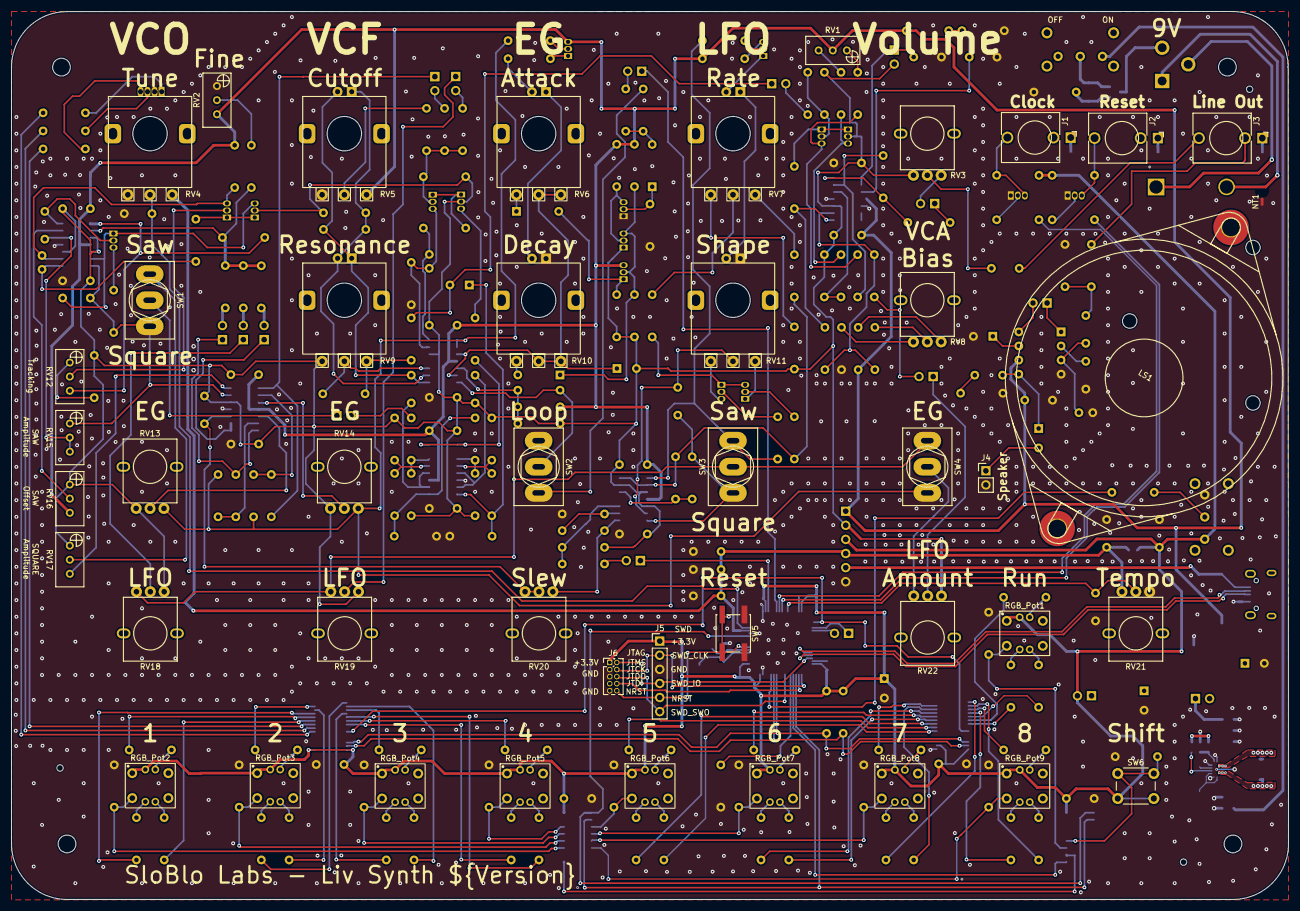
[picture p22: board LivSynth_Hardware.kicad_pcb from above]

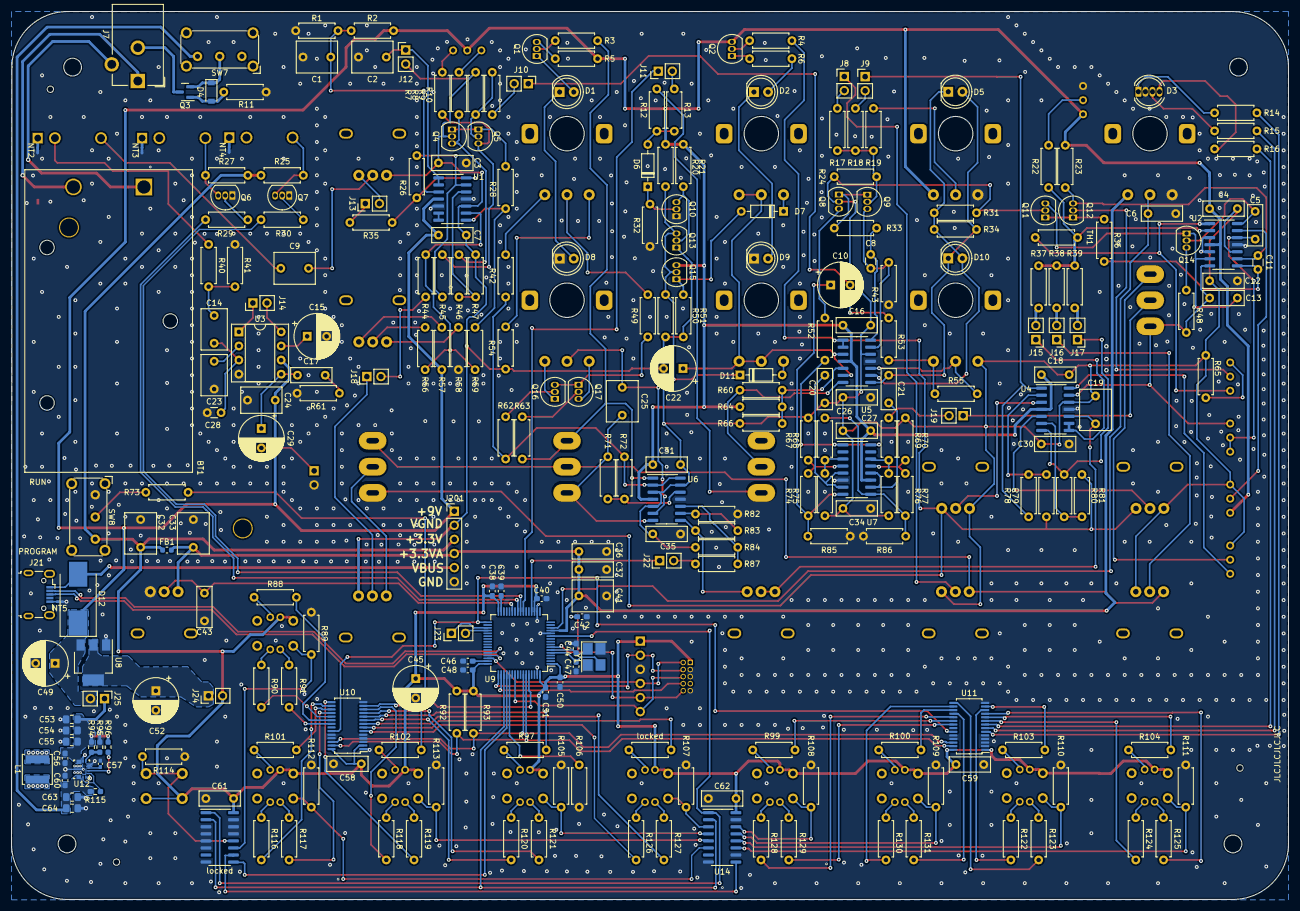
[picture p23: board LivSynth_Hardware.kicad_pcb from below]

Board: 2 copper layers, 230.0 x 159.9 mm, 320 parts (268 on the bottom side), 254 nets.

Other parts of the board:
locked: 220; R_Axial_DIN0207_L6.3mm_D2.5mm_P7.62mm_Horizontal
locked#2: 74HC165; SOIC-16_3.9x9.9mm_P1.27mm

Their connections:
+3.3V: locked#2.16 (VCC); also elsewhere on the board
/IO/BTN9: locked#2.11 (D0); also elsewhere on the board
/IO/BTN_SHIFT: locked#2.12 (D1); also elsewhere on the board
/IO/P5_G: locked.2; also elsewhere on the board
/IO/SR_SHLDN: locked#2.1 (~PL); also elsewhere on the board
/IO/SR_SPI_CLK: locked#2.2 (CP); also elsewhere on the board
/IO/SR_SPI_MISO: locked#2.9 (Q7); also elsewhere on the board
GND: locked#2.3 (D4), locked#2.4 (D5), locked#2.5 (D6), locked#2.6 (D7), locked#2.8 (GND), locked#2.13 (D2), locked#2.14 (D3), locked#2.15 (~CE); also elsewhere on the board
unnamed 208: locked.1; also elsewhere on the board
unnamed 253: locked#2.10 (DS); also elsewhere on the board

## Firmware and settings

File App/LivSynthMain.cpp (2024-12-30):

#include "LivSynthMain.h"
#include "main.h"
#include "swvPrint.h"
#include "System.h"
#include "ClockTimer.h"
#include "Clock.h"
#include "AdcInternal.h"
#include "DacInternal.h"
#include "Dio.h"
#include "ShiftRegister.h"
#include "ButtonMatrix.h"
#include "LEDDriver.h"
#include "Model.h"
#include "Engine.h"
#include "UiController.h"
#include <cmath>
#include "MidiHandler.h"

#define RUN_TEST 0

#define CCMRAM_BSS __attribute__((section(".ccmram")))

static CCMRAM_BSS ClockTimer    clockTimer;
                  AdcInternal   adc;
       CCMRAM_BSS DacInternal   dac;
       CCMRAM_BSS Dio           dio;
static CCMRAM_BSS ShiftRegister shiftRegister;
       CCMRAM_BSS ButtonMatrix  buttonMatrix(shiftRegister);
                  LEDDriver     ledDriver;
static            Model         model;
static CCMRAM_BSS MidiHandler   midiHandler;
static CCMRAM_BSS Engine        engine(model, clockTimer, midiHandler);
static CCMRAM_BSS UiController  uiController(model, engine);

void appMain() {

    if(RUN_TEST) testMain();

    System::init();
    clockTimer.init();
    dio.init();
    adc.init();
    dac.init();
    shiftRegister.init();
    buttonMatrix.init();
    ledDriver.init();
    midiHandler.init();
    engine.init();
    uiController.init();

    uint32_t curMillis
           , logMillis    = 0
           , engineMillis = 0;
    
    bool debug = false;
    
    bool updated = false;

    while(true) {

        curMillis = System::ticks();

        if(curMillis - engineMillis > 1) {
            //LL_GPIO_SetOutputPin(DBG1_GPIO_Port, DBG1_Pin);
            engineMillis = curMillis;
            updated = engine.update() || updated;

            buttonMatrix.process();
            uiController.handleControls(curMillis);

            if(updated || !engine.clockRunning()) {
                uiController.renderUI();
                ledDriver.process();
                updated = false;
            }
        	//LL_GPIO_ResetOutputPin(DBG1_GPIO_Port, DBG1_Pin);
        }
        
        // render debug log output
        if(debug && curMillis - logMillis > 999) {
            logMillis = curMillis;
            UDBG("Tempo = %.2f, RunState = %d\n", engine.tempo(), engine.runState());
            //DBG("ADC0=%d, ADC1=%d, bpm=%.2f, pitch=%.2f, buttons=0x%02X", adc.channel(0), adc.channel(1), _bpm, _pitch, shiftRegister.read());
        }
    }
}

// NVIC glue code
void appTick(void) {
    System::tick();
}

void appClockTimer() {
    clockTimer.notifyTimerUpdate();
}

void appLEDTxComplete() {
    ledDriver.notifyTxComplete();
}

void appLEDTxError() {
    ledDriver.notifyTxError();
}

void appADCCompleteRequest() {
    uiController.updateCV();
}

extern "C" {

void enqueueIncomingMidi(uint8_t *data) {
    //LL_GPIO_SetOutputPin(DBG2_GPIO_Port, DBG2_Pin);
    MidiUSBMessage umsg(data);
    MidiMessage msg;
    umsg.getMidiMessage(msg);
    midiHandler.enqueueIncoming(msg);
    //LL_GPIO_ResetOutputPin(DBG2_GPIO_Port, DBG2_Pin);
}

void midiTrxSentCallback() {
    midiHandler.setBusy(false);
}

}

/*#######################################
   A fun test application to check
     MCU peripherals and devices
#######################################*/
void testMain() {
    System::init();
    clockTimer.init();
    dio.init();
    adc.init();
    dac.init();
    shiftRegister.init();
    buttonMatrix.init();
    ledDriver.init();

    uint32_t curMillis
           , logMillis    = 0
           , updateMillis = 0;
    
    KeyState _keyState;
    _keyState.reset();

    uint8_t demoStyle = 0;

    while(true) {

        curMillis = System::ticks();

        if(curMillis - updateMillis > 79) {
            updateMillis = curMillis;

            buttonMatrix.process();

            uint16_t tune = adc.channel(0);
            uint16_t tempo = adc.channel(1);

            dac.setValue(tune);
            
            if(demoStyle == 0) {
                float delta = 4095.0 / 10;
                uint8_t k = floorf(tune / delta + .5f);
                
                float H = tempo / 4095. * 360;
    
                for(uint8_t button = 0; button < 10; ++button) {
                    ledDriver.setColourHSV(button, H, 1.f, button < k ? 1. : 0.);
                }
                
                static float hue = 0.f;
                hue += 10;
                if(hue >= 360.f) hue -= 360.f;
    
                ButtonMatrix::Event event;
                while(buttonMatrix.nextEvent(event)) {
                    bool isDown = event.action() == ButtonMatrix::Event::KeyDown;
    
                    DBG("action=%d, value=%d", event.action(), event.value());
                    _keyState[event.value()] = isDown;
                    Key key(event.value(), _keyState);
                    float value = isDown ? 1. : 0.;
                    if(key.isStep()) {
                        ledDriver.setColourHSV(event.value() + 1, hue, 1.f, value);
                    } else if(key.isPlay()) {
                        ledDriver.setColourHSV(RGBLed::Code::Play, hue, 1.f, value);
                        dio.setGate(isDown);
                    } else if(key.isShift()) {
                        ledDriver.setColourHSV(RGBLed::Code::Tune, hue, 1.f, value);
                        if(!isDown)
                            demoStyle = 1;
                    }
                }
            } else if(demoStyle == 1) {
                float saturation = tune / 4095.f;
                float value      = tempo / 4095.f;

                for(uint8_t led = 0; led < 11; ++led) {
                    ledDriver.setColourHSV(led, 0.f, saturation, value);
                }

                ButtonMatrix::Event event;
                while(buttonMatrix.nextEvent(event)) {
                    bool isDown = event.action() == ButtonMatrix::Event::KeyDown;
    
                    DBG("action=%d, value=%d", event.action(), event.value());
                    _keyState[event.value()] = isDown;
                    Key key(event.value(), _keyState);
                    if(key.isStep()) {
                        //ledDriver.setColourHSV(event.value() + 1, 0.f, saturation, value);
                    } else if(key.isPlay()) {
                        //ledDriver.setColourHSV(RGBLed::Code::Play, 0.f, saturation, value);
                        dio.setGate(isDown);
                    } else if(key.isShift()) {
                        ledDriver.setColourHSV(RGBLed::Code::Tune, 0.f, saturation, value);
                        if(!isDown)
                            demoStyle = 0;
                    }
                }
            }

            ledDriver.process();
            dio.update();
            dac.update();

            LL_GPIO_TogglePin(CLOCK_OUT_GPIO_Port, CLOCK_OUT_Pin);

        }
        
        // render debug log output
        if(curMillis - logMillis > 999) {
            logMillis = curMillis;
            DBG("Tune_ADC=%d, Tempo_ADC=%d", adc.channel(0), adc.channel(1));
            LL_GPIO_TogglePin(RESET_OUT_GPIO_Port, RESET_OUT_Pin);
        }
    }
}

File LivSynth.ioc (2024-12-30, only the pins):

Mcu.UserName=STM32F405RGTx
PA0-WKUP.GPIO_Label=ADC_IN1
PA0-WKUP.Signal=ADCx_IN0
PA11.Signal=USB_OTG_FS_DM
PA12.Signal=USB_OTG_FS_DP
PA13.Signal=SYS_JTMS-SWDIO
PA14.Signal=SYS_JTCK-SWCLK
PA4.Signal=COMP_DAC1_group
PA7.GPIO_Label=GATE_OUT
PA7.Signal=GPIO_Output
PB1.GPIO_Label=ADC_IN2
PB1.Signal=ADCx_IN9
PB12.GPIO_Label=LED_OEN
PB12.Signal=GPIO_Output
PB14.GPIO_Label=DBG1
PB14.Signal=GPIO_Output
PB15.GPIO_Label=DBG2
PB15.Signal=GPIO_Output
PB3.Signal=SYS_JTDO-SWO
PB6.Signal=I2C1_SCL
PB7.Signal=I2C1_SDA
PC10.GPIO_Label=SPI_SCK
PC10.Signal=SPI3_SCK
PC11.GPIO_Label=SPI_MISO
PC11.Signal=SPI3_MISO
PC12.GPIO_Label=SPI_MOSI
PC12.Signal=SPI3_MOSI
PC3.GPIO_Label=SR_SHLDN
PC3.Signal=GPIO_Output
PC4.GPIO_Label=CLOCK_OUT
PC4.Signal=GPIO_Output
PC5.GPIO_Label=RESET_OUT
PC5.Signal=GPIO_Output
PH0-OSC_IN.Signal=RCC_OSC_IN
PH1-OSC_OUT.Signal=RCC_OSC_OUT

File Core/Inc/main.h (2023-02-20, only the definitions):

#define SR_SHLDN_Pin LL_GPIO_PIN_3
#define SR_SHLDN_GPIO_Port GPIOC
#define ADC_IN1_Pin LL_GPIO_PIN_0
#define ADC_IN1_GPIO_Port GPIOA
#define GATE_OUT_Pin LL_GPIO_PIN_7
#define GATE_OUT_GPIO_Port GPIOA
#define CLOCK_OUT_Pin LL_GPIO_PIN_4
#define CLOCK_OUT_GPIO_Port GPIOC
#define RESET_OUT_Pin LL_GPIO_PIN_5
#define RESET_OUT_GPIO_Port GPIOC
#define ADC_IN2_Pin LL_GPIO_PIN_1
#define ADC_IN2_GPIO_Port GPIOB
#define LED_OEN_Pin LL_GPIO_PIN_12
#define LED_OEN_GPIO_Port GPIOB
#define DBG1_Pin LL_GPIO_PIN_14
#define DBG1_GPIO_Port GPIOB
#define DBG2_Pin LL_GPIO_PIN_15
#define DBG2_GPIO_Port GPIOB
#define SPI_SCK_Pin LL_GPIO_PIN_10
#define SPI_SCK_GPIO_Port GPIOC
#define SPI_MISO_Pin LL_GPIO_PIN_11
#define SPI_MISO_GPIO_Port GPIOC
#define SPI_MOSI_Pin LL_GPIO_PIN_12
#define SPI_MOSI_GPIO_Port GPIOC

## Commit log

2022-07-30 initial upload
    [EG.kicad_sch, IO.kicad_sch, LFO.kicad_sch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]
2022-07-30 Fill all title blocks
    [MCU.kicad_sch, ModMatrix.kicad_sch, Power.kicad_sch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]
2022-09-04 Initial Routing finished
    [EG.kicad_sch, IO.kicad_sch, LFO.kicad_sch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]
2022-09-09 Rework for polyester film capacitors
    [EG.kicad_sch, IO.kicad_sch, LFO.kicad_sch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]
2022-09-09 Silkscreen cosmetics
2022-09-09 Additional Silkscreen Cosmetics
    [LivSynth_Hardware-B_Cu.gbr, LivSynth_Hardware-B_Mask.gbr, LivSynth_Hardware-B_Paste.gbr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]
2022-09-13 Change LED status circuits
    [EG.kicad_sch, IO.kicad_sch, LFO.kicad_sch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]
2022-09-14 White balance for RGB LEDs
    [IO.kicad_sch, LFO.kicad_sch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]
2022-09-14 White balance for RGB LEDs (update comments)
    [LivSynth_Hardware.kicad_sch]
2022-09-19 Adjust crystal cap values Add BOM csv
    [LivSynth_Hardware.csv, LivSynth_Hardware.dsn, LivSynth_Hardware.kicad_sch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]
2022-09-24 Use correct Elko sizes (8mm/3.5mm)
    [IO.kicad_sch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]
2022-09-30 0v1 Ready for Production
    [EG.kicad_sch, IO.kicad_sch, LFO.kicad_sch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]
2022-11-13 Start Testing the prototype
    [EG.kicad_sch, IO.kicad_sch, LFO.kicad_sch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]
2022-11-13 Add sources from LivSynth_Nucleo and fix the build
    [LivSynth_Hardware.kicad_sch]
2022-11-20 LEDs working DFU connection from HS to FS
    [LivSynth_Hardware.kicad_sch]
2022-11-20 Compatibility for STM32CubeIDE
2022-11-24 ButtonMatrix working debug launch configuration added shift register moved to full-duplex mode (simplex does not support triggering the latch line and puts too much stress on the operation) Hardware 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
    [LivSynth_Hardware.kicad_sch]
2022-11-24 ADC working ITM Debug print working
2022-11-24 dio working (fixing inversion bug in button matrix processor)
    [LivSynthMain.cpp]
2022-11-25 Sequencer engine working
    [LivSynth_Hardware.kicad_sch]
2022-11-25 Reset pulse added
    [LivSynth_Hardware.kicad_sch]
2022-12-03 Stop making noise upon startup
    [LivSynthMain.cpp]
2022-12-04 Before fixing HW issues
    [IO.kicad_sch, LivSynth_Hardware.kicad_sch]
2022-12-07 Analog redesign: - Power: Add voltage and current test points - MCU: use PA11/PA12 for USB DFU interface - MCU: add NRST reset switch - Slew: increase portamento cap - VCO: invert trim pots - VCF: le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
    [EG.kicad_sch, IO.kicad_sch, LFO.kicad_sch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]
2023-01-07 Analog Redesign: - Power: Build ververse polarity protection using P-Mosfet and Zener Diode - (https://www.youtube.com/watch?v=Ltx4vovY5Z4 - 1:28) - Power: Build adjustable buck regulator for 8-9V st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
    [EG.kicad_sch, IO.kicad_sch, LFO.kicad_sch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]
2023-01-08 Keep selected note always active for editing Fix annoying gate issue
    [LivSynth_Hardware.kicad_sch]
2023-01-21 progress 2023-01-21
    [EG.kicad_sch, IO.kicad_sch, LFO.kicad_sch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]
2023-01-21 DRC: no severe errors
    [LivSynth_Hardware.kicad_sch, MCU.kicad_sch]
2023-01-28 LCSC component looked up
    [IO.kicad_sch, LivSynth_Hardware.kicad_sch, MCU.kicad_sch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]
2023-01-28 Add gerbers and bom
    [LivSynth_Hardware-B_Cu.gbr, LivSynth_Hardware-B_Mask.gbr, LivSynth_Hardware-B_Paste.gbr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]
2023-01-29 Prepare for JLC order, manual correction tps63070
    [LivSynth_Hardware-B_Cu.gbr, LivSynth_Hardware-B_Mask.gbr, LivSynth_Hardware-B_Paste.gbr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]
2023-01-29 Geographical reannotate
    [EG.kicad_sch, IO.kicad_sch, LFO.kicad_sch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]
2023-01-29 Order placement 2023-01-29
    [IO.kicad_sch, LivSynth_Hardware.kicad_sch, Power.kicad_sch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]
2023-01-30 Modify toggle switches (footprint and 3D model) Align R value designators Add JLC component placement checkup file
    [EG.kicad_sch, IO.kicad_sch, LivSynth_Hardware.kicad_sch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]
2023-01-31 Create new 0v3 folder
    [EG.kicad_sch, IO.kicad_sch, LFO.kicad_sch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]
2023-02-17 switch to KiCad 7
2023-02-20 adapt drivers to mcu connection reconfiguration
2023-02-26 Suppress new CMake warning on RWX segments Add 2nd demo option Flush pending gates on sequencer stop Improve keyboard performance mode Add chromatic quantization Reflect 0v2 RGB led mapping Impove UI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
2023-02-26 Start working on faceplate All holes for frontend components added
    [LivSynth_Faceplate.kicad_pcb]
2023-02-28 Speaker grill ready Test knob spin silkscreen with KiCad tools
    [LivSynth_Faceplate.kicad_pcb]
2023-03-01 Algorithmic Speaker Grill added
    [LivSynth_Faceplate.kicad_pcb]
2023-03-02 Back to sequence when all buttons are released
2023-03-12 Faceplate 2023-03-12
    [LivSynth_Faceplate.kicad_pcb]
2023-03-13 Retain silkscreen in front of foto with soldermask
2023-03-15 Add version tag on backside Add silkscreen space around switches
    [bom.csv, designators.csv, positions.csv]
2023-03-25 Reduce EG cap to 4u7 Reduce LFO cap to 220n VCO R23: 470K, C13: 10n
    [EG.kicad_sch, IO.kicad_sch, LFO.kicad_sch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]
2023-03-26 Update speaker footprint
2023-03-29 EG: raise Rf of comparator circuit to improve performance LFO: raise coupling resistor for higher amplitude, adapt cap for more musical ranges
    [EG.kicad_sch, LFO.kicad_sch, LivSynth_Hardware.kicad_sch]
2023-03-29 Add another LFO cap for easier modding please MCU connectors to the backside Relocate reset button KiCad 7.0.1
    [EG.kicad_sch, IO.kicad_sch, LFO.kicad_sch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]
2023-03-30 Increase loudness
    [VCA.kicad_sch]
2023-03-30 Apply loudness patch to 0v3
    [VCA.kicad_sch]
2023-03-30 Optimize input handling Blank default track fix quantization issue
    [LivSynthMain.cpp]
2023-04-12 RV11 = 100K update BOM RV2 = 100K C13 = 10n R23 = 470K
    [LFO.kicad_sch, LivSynth_Hardware.csv, LivSynth_Hardware.kicad_sch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]
2023-04-12 Normalize hardware file structure
    [EG.kicad_sch, IO.kicad_sch, LFO.kicad_sch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]
2023-04-12 remove 0v3 subfolder
    [EG.kicad_sch, IO.kicad_sch, LFO.kicad_sch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]
2023-04-12 add 0v2 status
    [EG.kicad_sch, IO.kicad_sch, LFO.kicad_sch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]
2023-04-12 publish new hardware folder structure
    [EG.kicad_sch, IO.kicad_sch, LFO.kicad_sch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]
2023-04-16 Backport from 0v3
    [LFO.kicad_sch, LivSynth_Hardware.kicad_sch, VCO.kicad_sch]
2023-04-16 Update BOM with changes from 0v3
    [LivSynth_Hardware.csv]
2023-04-17 exxclude pre-assebled and not required components from BOM
    [IO.kicad_sch, LivSynth_Hardware.csv, MCU.kicad_sch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]
2023-04-17 exclude reset switch from BOM
    [LivSynth_Hardware.csv, MCU.kicad_sch]
2023-04-22 Remove 0v1 schematics Add 0v2 schematic pdf
    [EG.kicad_sch, IO.kicad_sch, LFO.kicad_sch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]
2023-06-06 Create MIDI/CDC USB Composite device
2023-09-14 Rename Decay -> Release
    [EG.kicad_sch, LivSynth_Hardware.kicad_sch]
2024-12-29 Fix slave mode sync issue Upgrade to MxCube Version 6.13.0 and STM32Cube 1.28.1 Release v0.2.4
    [LivSynth Debug.cfg]

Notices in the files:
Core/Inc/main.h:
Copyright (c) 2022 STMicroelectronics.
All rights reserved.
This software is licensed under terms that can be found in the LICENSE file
